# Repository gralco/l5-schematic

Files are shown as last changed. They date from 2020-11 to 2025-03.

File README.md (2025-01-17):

# l5-schematic

The Librem 5 schematics and layout files (mainboard, USB-C board, and USB-C FPC flex cable).

The [EDA CAD files](./CAD/) included are the [PADS](./CAD/PADS/) schematic and layout that were used to produce the Librem 5 boards,
as well as [KiCad](./CAD/KiCad/) files which are a converted capture of the PADS design that are in a reliable reference draft state.

## License
[GNU GPLv3+](./LICENSE)

## Mechanical Designs
The Librem 5's mechanical designs can be found in the [Librem5/3D_designs](https://source.puri.sm/Librem5/3D_designs) repo.

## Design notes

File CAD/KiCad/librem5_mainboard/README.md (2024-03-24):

# Librem 5 Mainboard KiCad Conversion
Project to convert the Librem 5 Mainboard to KiCad.

## License
GNU GPLv3+

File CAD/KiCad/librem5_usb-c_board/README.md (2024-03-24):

# Librem 5 USB-C Board KiCad Conversion
Project to convert the Librem 5 USB-C board to KiCad.

## License
GNU GPLv3+

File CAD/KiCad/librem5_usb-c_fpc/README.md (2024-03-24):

# Librem 5 USB-C FPC KiCad Conversion
Project to convert the Librem 5 USB-C FPC to KiCad.

## License
GNU GPLv3+

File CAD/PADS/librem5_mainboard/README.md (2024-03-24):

# Librem 5 Mainboard PADS
The Librem 5 Mainboard PADS CAD files.

## License
GNU GPLv3+

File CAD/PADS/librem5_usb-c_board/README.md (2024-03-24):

# Librem 5 USB-C Board PADS
The Librem 5 USB-C board PADS CAD files.

## License
GNU GPLv3+

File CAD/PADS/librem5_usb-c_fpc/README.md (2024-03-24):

# Librem 5 USB-C FPC PADS
The Librem 5 USB-C FPC PADS CAD files.

## License
GNU GPLv3+

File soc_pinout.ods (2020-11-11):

Net Name | Specific Alt Def | Ball name | PAD TYPE | Alt0 | Alt1 | Alt2 | Alt3 | Alt4 | Alt5 | Alt6 | Alt7
VSS | N/A | A2 | Ground
BT_WAKE | gpio4.IO[20] (interrupt) | A3 | GPIO | sai1.MCLK | sai5.MCLK | sai1.TX_BCLK |  |  | gpio4.IO[20] |  | sim_m.HRESP
FLASH_MOSI | ecspi1.MOSI | A4 | GPIO | ecspi1.MOSI | uart3.TX |  |  |  | gpio5.IO[7] |  | tpsmp.HDATA[9]
UART4_RTS | uart4.RTS_B | A5 | GPIO | ecspi2.SS0 | uart4.RTS_B |  |  |  | gpio5.IO[13] |  | tpsmp.HDATA[15]
UART3_RXD | uart3.RX | A6 | GPIO | uart3.RX | uart1.CTS_B |  |  |  | gpio5.IO[26] |  | tpsmp.HDATA[28]
UART1_TXD | uart1.TX | A7 | GPIO | uart1.TX | ecspi3.MOSI |  |  |  | gpio5.IO[23] |  | tpsmp.HDATA[25]
NC (pin USB2_RX_P) | NC | A8 | PHY
NC (pin USB2_TX_P) | NC | A9 | PHY
USB2_DP | N/A | A10 | PHY
USB1_RESREF | N/A | A11 | Ground
USB1_RXP | N/A | A12 | PHY
USB1_TXP | N/A | A13 | PHY
USB1_DP | N/A | A14 | PHY
DSI_DN3 | N/A | A15 | PHY
DSI_DN1 | N/A | A16 | PHY
DSI_DN0 | N/A | A17 | PHY
DSI_DN2 | N/A | A18 | PHY
CSI_P2_CKN | N/A | A19 | PHY
CSI_P2_DN1 | N/A | A20 | PHY
CSI_P2_DN2 | N/A | A21 | PHY
CSI_P1_CKN | N/A | A22 | PHY
CSI_P1_DN0 | N/A | A23 | PHY
VSS | N/A | A24 | Ground
VSS | N/A | B1 | Ground
Unpurposed (BOOT_CFG10/SAI1_TXD2) | gpio4.IO[14] (output LOW) | B2 | GPIO | sai1.TX_DATA[2] | sai5.TX_DATA[2] |  |  | coresight.TRACE[10] | gpio4.IO[14] | ccmsrcgpcmix.BOOT_CFG[10] | sim_m.HADDR[29]
Unpurposed (BOOT_CFG14/SAI1_TXD6) | gpio4.IO[18] (output LOW) | B3 | GPIO | sai1.TX_DATA[6] | sai6.RX_SYNC | sai6.TX_SYNC |  | coresight.TRACE[14] | gpio4.IO[18] | ccmsrcgpcmix.BOOT_CFG[14] | sim_m.HBURST[1]
FLASH_MISO | ecspi1.MISO | B4 | GPIO | ecspi1.MISO | uart3.CTS_B |  |  |  | gpio5.IO[8] |  | tpsmp.HDATA[10]
UART4_CTS | uart4.CTS_B | B5 | GPIO | ecspi2.MISO | uart4.CTS_B |  |  |  | gpio5.IO[12] |  | tpsmp.HDATA[14]
UART2_RXD | uart2.RX | B6 | GPIO | uart2.RX | ecspi3.MISO |  |  |  | gpio5.IO[24]
UART3_TXD | uart3.TX | B7 | GPIO | uart3.TX | uart1.RTS_B |  |  |  | gpio5.IO[27] |  | tpsmp.HDATA[29]
NC (pin USB2_RX_N) | NC | B8 | PHY
NC (pin USB2_TX_N) | NC | B9 | PHY
USB2_DN | N/A | B10 | PHY
USB2_RESREF | N/A | B11 | Ground
USB1_RXN | N/A | B12 | PHY
USB1_TXN | N/A | B13 | PHY
USB1_DN | N/A | B14 | PHY
DSI_DP3 | N/A | B15 | PHY
DSI_DP1 | N/A | B16 | PHY
DSI_DP0 | N/A | B17 | PHY
DSI_DP2 | N/A | B18 | PHY
CSI_P2_CKP | N/A | B19 | PHY
CSI_P2_DP1 | N/A | B20 | PHY
CSI_P2_DP2 | N/A | B21 | PHY
CSI_P1_CKP | N/A | B22 | PHY
CSI_P1_DP0 | N/A | B23 | PHY
CSI_P1_DN2 | N/A | B24 | PHY
VSS | N/A | B25 | Ground
Unpurposed (BOOT_CFG15/SAI1_TXD7) | gpio4.IO[19] (output LOW) | C1 | GPIO | sai1.TX_DATA[7] | sai6.MCLK |  |  | coresight.TRACE[15] | gpio4.IO[19] | ccmsrcgpcmix.BOOT_CFG[15] | sim_m.HBURST[2]
SAI6_TXD0 (BOOT_CFG13) | sai6.TX_DATA[0] | C2 | GPIO | sai1.TX_DATA[5] | sai6.RX_DATA[0] | sai6.TX_DATA[0] |  | coresight.TRACE[13] | gpio4.IO[17] | ccmsrcgpcmix.BOOT_CFG[13] | sim_m.HBURST[0]
SAI3_TXD | sai3.TX_DATA[0] | C3 | GPIO | sai3.TX_DATA[0] | gpt1.CAPTURE3 | sai5.RX_DATA[3] |  |  | gpio5.IO[1]
SAI3_TXC | sai3.TX_BCLK | C4 | GPIO | sai3.TX_BCLK | gpt1.CAPTURE2 | sai5.RX_DATA[2] |  |  | gpio5.IO[0]
UART4_RXD | uart4.RX | C5 | GPIO | ecspi2.SCLK | uart4.RX |  |  |  | gpio5.IO[10] |  | tpsmp.HDATA[12]
SPI_SS1 | gpio5.IO[28] (output) | C6 | GPIO | uart4.RX | uart2.CTS_B | pcie1.CLKREQ_B |  |  | gpio5.IO[28]
UART1_RXD | uart1.RX | C7 | GPIO | uart1.RX | ecspi3.SCLK |  |  |  | gpio5.IO[22] |  | tpsmp.HDATA[24]
VSS | N/A | C8 | Ground
USB2_ID | N/A | C9 | PHY
VSS | N/A | C10 | Ground
USB2_VPTX | N/A | C11 | Power
USB1_VPTX | N/A | C12 | Power
VSS | N/A | C13 | Ground
USB1_ID | N/A | C14 | PHY
VSS | N/A | C15 | Ground
DSI_CKN | N/A | C16 | PHY
MIPI_DSI_REXT | N/A | C17 | Ground
MIPI_VDDHA1 | N/A | C18 | Power
CSI_P2_DN3 | N/A | C19 | PHY
CSI_P2_DN0 | N/A | C20 | PHY
CSI_P1_DN3 | N/A | C21 | PHY
CSI_P1_DN1 | N/A | C22 | PHY
CSI_P1_DP2 | N/A | C23 | PHY
VSS | N/A | C24 | Ground
PCIE2_RESREF | N/A | C25 | NC
Unpurposed (BOOT_CFG11/SAI1_TXD3) | gpio4.IO[15] (output LOW) | D1 | GPIO | sai1.TX_DATA[3] | sai5.TX_DATA[3] |  |  | coresight.TRACE[11] | gpio4.IO[15] | ccmsrcgpcmix.BOOT_CFG[11] | sim_m.HADDR[30]
SAI6_RXC (BOOT_CFG12) | sai6.RX_BCLK | D2 | GPIO | sai1.TX_DATA[4] | sai6.RX_BCLK | sai6.TX_BCLK |  | coresight.TRACE[12] | gpio4.IO[16] | ccmsrcgpcmix.BOOT_CFG[12] | sim_m.HADDR[31]
LED_G | pwm4.OUT | D3 | GPIO | sai3.MCLK | pwm4.OUT | sai5.MCLK |  |  | gpio5.IO[2]
FLASH_SS | ecspi1.SS0 | D4 | GPIO | ecspi1.SS0 | uart3.RTS_B |  |  |  | gpio5.IO[9] |  | tpsmp.HDATA[11]
FLASH_SCK | ecspi1.SCLK | D5 | GPIO | ecspi1.SCLK | uart3.RX |  |  |  | gpio5.IO[6] |  | tpsmp.HDATA[8]
UART2_TXD | uart2.TX | D6 | GPIO | uart2.TX | ecspi3.SS0 |  |  |  | gpio5.IO[25]
SMC_BOOT0 | gpio5.IO[29] (output) | D7 | GPIO | uart4.TX | uart2.RTS_B | pcie2.CLKREQ_B |  |  | gpio5.IO[29]
NVCC_UART | N/A | D8 | Power
USB2_VBUS | N/A | D9 | PHY
VSS | N/A | D10 | Ground
USB2_VP | N/A | D11 | Power
USB1_VP | N/A | D12 | Power
VSS | N/A | D13 | Ground
USB1_VBUS | N/A | D14 | PHY
VSS | N/A | D15 | Ground
DSI_CKP | N/A | D16 | PHY
MIPI_VDDHA2 | N/A | D17 | Power
MIPI_VDDHA3 | N/A | D18 | Power
CSI_P2_DP3 | N/A | D19 | PHY
CSI_P2_DP0 | N/A | D20 | PHY
CSI_P1_DP3 | N/A | D21 | PHY
CSI_P1_DP1 | N/A | D22 | PHY
VSS | N/A | D23 | Ground
NC (pin PCIE2_RXN_N) | NC | D24 | PHY
NC (pin PCIE2_RXN_P) | NC | D25 | PHY
NFC_IRQ | gpio4.IO[11] (interrupt) | E1 | GPIO | sai1.TX_BCLK | sai5.TX_BCLK |  |  | coresight.EVENTI | gpio4.IO[11] |  | sim_m.HADDR[26]
Unpurposed (BOOT_CFG09/SAI1_TXD1) | gpio4.IO[13] (output LOW) | E2 | GPIO | sai1.TX_DATA[1] | sai5.TX_DATA[1] |  |  | coresight.TRACE[9] | gpio4.IO[13] | ccmsrcgpcmix.BOOT_CFG[9] | sim_m.HADDR[28]
NVCC_SAI3 | N/A | E3 | Power
VSS | N/A | E4 | Ground
UART4_TXD | uart4.TX | E5 | GPIO | ecspi2.MOSI | uart4.TX |  |  |  | gpio5.IO[11] |  | tpsmp.HDATA[13]
MOTO (haptic) | pwm1.OUT | E6 | GPIO | spdif1.EXT_CLK | pwm1.OUT |  |  |  | gpio5.IO[5] |  | tpsmp.HDATA[7]
I2C1_SCL_1V8 | i2c1.SCL | E7 | GPIO | i2c1.SCL | enet1.MDC |  |  |  | gpio5.IO[14] |  | tpsmp.HDATA[16]
I2C1_SDA_1V8 | i2c1.SDA | E8 | GPIO | i2c1.SDA | enet1.MDIO |  |  |  | gpio5.IO[15] |  | tpsmp.HDATA[17]
I2C3_SDA | i2c3.SDA | E9 | GPIO | i2c3.SDA | pwm3.OUT | gpt3.CLK |  |  | gpio5.IO[19] |  | tpsmp.HDATA[21]
VSS | N/A | E10 | Ground
USB2_DVDD | N/A | E11 | Power
USB1_DVDD | N/A | E12 | Power
VSS | N/A | E13 | Ground
VSS | N/A | E14 | Ground
MIPI_VDD1 | N/A | E15 | Power
VSS | N/A | E16 | Ground
MIPI_VDDA1 | N/A | E17 | Power
MIPI_VDDA2 | N/A | E18 | Power
VSS | N/A | E19 | Ground
VSS | N/A | E20 | Ground
VSS | N/A | E21 | Ground
VSS | N/A | E22 | Ground
VSS | N/A | E23 | Ground
NC (pin PCIE2_TXN_N) | NC | E24 | PHY
NC (pin PCIE2_TXN_P) | NC | E25 | PHY
SAI6_RXD0 (BOOT_CFG05) | sai6.RX_DATA[0] | F1 | GPIO | sai1.RX_DATA[5] | sai6.TX_DATA[0] | sai6.RX_DATA[0] | sai1.RX_SYNC | coresight.TRACE[5] | gpio4.IO[7] | ccmsrcgpcmix.BOOT_CFG[5] | sim_m.HADDR[22]
Unpurposed (BOOT_CFG08/SAI1_TXD0) | gpio4.IO[12] (output LOW) | F2 | GPIO | sai1.TX_DATA[0] | sai5.TX_DATA[0] |  |  | coresight.TRACE[8] | gpio4.IO[12] | ccmsrcgpcmix.BOOT_CFG[8] | sim_m.HADDR[27]
SAI3_RXD | sai3.RX_DATA[0] | F3 | GPIO | sai3.RX_DATA[0] | gpt1.CAPTURE1 | sai5.RX_DATA[0] |  |  | gpio4.IO[30]
WIFI_REG_ON | gpio4.IO[29] (output) | F4 | GPIO | sai3.RX_BCLK | gpt1.CAPTURE2 | sai5.RX_BCLK |  |  | gpio4.IO[29] |  | tpsmp.HTRANS[1]
NVCC_ECSPI | N/A | F5 | Power
LED_R | pwm3.OUT | F6 | GPIO | spdif1.OUT | pwm3.OUT |  |  |  | gpio5.IO[3] |  | tpsmp.HDATA[5]
I2C2_SDA | i2c2.SDA | F7 | GPIO | i2c2.SDA | enet1.1588_EVENT1_OUT |  |  |  | gpio5.IO[17] |  | tpsmp.HDATA[19]
I2C4_SCL | i2c4.SCL | F8 | GPIO | i2c4.SCL | pwm2.OUT | pcie1.CLKREQ_B |  |  | gpio5.IO[20] |  | tpsmp.HDATA[22]
I2C4_SDA | i2c4.SDA | F9 | GPIO | i2c4.SDA | pwm1.OUT | pcie2.CLKREQ_B |  |  | gpio5.IO[21] |  | tpsmp.HDATA[23]
VSS | N/A | F10 | Ground
USB2_VPH | N/A | F11 | Power
USB1_VPH | N/A | F12 | Power
VSS | N/A | F13 | Ground
VSS | N/A | F14 | Ground
MIPI_VDD1 | N/A | F15 | Power
VSS | N/A | F16 | Ground
MIPI_VDDA3 | N/A | F17 | Power
MIPI_VDDA4 | N/A | F18 | Power
MIPI_VDDPLL | N/A | F19 | Power
VSS | N/A | F20 | Ground
CHG_INT | gpio3.IO[3] (interrupt) | F21 | GPIO | rawnand.CE2_B | qspi.B_SS0_B |  |  |  | gpio3.IO[3]
PCIE_VP2 | N/A | F22 | NC
PCIE_VPTX2 | N/A | F23 | NC
NC (pin PCIE2_REF_PAD_CLK_N) | NC | F24 | PHY
NC (pin PCIE2_REF_PAD_CLK_P) | NC | F25 | PHY
Unpurposed (BOOT_CFG07/SAI1_RXD7) | gpio4.IO[9] (output LOW) | G1 | GPIO | sai1.RX_DATA[7] | sai6.MCLK | sai1.TX_SYNC | sai1.TX_DATA[4] | coresight.TRACE[7] | gpio4.IO[9] | ccmsrcgpcmix.BOOT_CFG[7] | sim_m.HADDR[24]
SAI6_RXFS (BOOT_CFG06) | sai6.RX_SYNC | G2 | GPIO | sai1.RX_DATA[6] | sai6.TX_SYNC | sai6.RX_SYNC |  | coresight.TRACE[6] | gpio4.IO[8] | ccmsrcgpcmix.BOOT_CFG[6] | sim_m.HADDR[23]
SAI3_TXFS | sai3.TX_SYNC | G3 | GPIO | sai3.TX_SYNC | gpt1.CLK | sai5.RX_DATA[1] |  |  | gpio4.IO[31]
NFC_EN | gpio4.IO[28] | G4 | GPIO | sai3.RX_SYNC | gpt1.CAPTURE1 | sai5.RX_SYNC |  |  | gpio4.IO[28]
SAI2_TXD | sai2.TX_DATA[0] | G5 | GPIO | sai2.TX_DATA[0] | sai5.TX_DATA[3] |  |  |  | gpio4.IO[26] |  | tpsmp.CLK
SPDIF_RX | gpio5.IO[4] (output) | G6 | GPIO | spdif1.IN | pwm2.OUT |  |  |  | gpio5.IO[4] |  | tpsmp.HDATA[6]
I2C2_SCL | i2c2.SCL | G7 | GPIO | i2c2.SCL | enet1.1588_EVENT1_IN |  |  |  | gpio5.IO[16] |  | tpsmp.HDATA[18]
I2C3_SCL | i2c3.SCL | G8 | GPIO | i2c3.SCL | pwm4.OUT | gpt2.CLK |  |  | gpio5.IO[18] |  | tpsmp.HDATA[20]
VSS | N/A | G9 | Ground
VSS | N/A | G10 | Ground
USB2_VDD33 | N/A | G11 | Power
USB1_VDD33 | N/A | G12 | Power
VSS | N/A | G13 | Ground
VDD_ARM | N/A | G14 | Power
VDD_ARM | N/A | G15 | Power
VDD_ARM | N/A | G16 | Power
VSS | N/A | G17 | Ground
VSS | N/A | G18 | Ground
NC (pin NAND_ALE) | gpio3.IO[0] (output LOW) | G19 | GPIO | rawnand.ALE | qspi.A_SCLK |  |  |  | gpio3.IO[0] |  | sim_m.HPROT[0]
NC (pin NAND_DATA00) | gpio3.IO[6] (output LOW) | G20 | GPIO | rawnand.DATA00 | qspi.A_DATA[0] |  |  |  | gpio3.IO[6]
CHG_EN | gpio3.IO[2] (output) | G21 | GPIO | rawnand.CE1_B | qspi.A_SS1_B |  |  |  | gpio3.IO[2] |  | sim_m.HPROT[2]
PCIE_VP1 | N/A | G22 | NC
PCIE_VPTX1 | N/A | G23 | NC
VSS | N/A | G24 | Ground
PCIE1_RESREF | N/A | G25 | NC
HSW_WIFI_STATE | gpio4.IO[10] (input) | H1 | GPIO | sai1.TX_SYNC | sai5.TX_SYNC |  |  | coresight.EVENTO | gpio4.IO[10] |  | sim_m.HADDR[25]
Unpurposed (BOOT_CFG02/SAI1_RXD2) | gpio4.IO[4] (output LOW) | H2 | GPIO | sai1.RX_DATA[2] | sai5.RX_DATA[2] |  |  | coresight.TRACE[2] | gpio4.IO[4] | ccmsrcgpcmix.BOOT_CFG[2] | sim_m.HADDR[19]
NC (pin SAI2_RXC) | gpio4.IO[22] (output LOW) | H3 | GPIO | sai2.RX_BCLK | sai5.TX_BCLK |  |  |  | gpio4.IO[22] |  | sim_m.HSIZE[1]
SAI2_TXFS | sai2.TX_SYNC | H4 | GPIO | sai2.TX_SYNC | sai5.TX_DATA[1] |  |  |  | gpio4.IO[24] |  | sim_m.HWRITE
SAI2_MCLK | sai2.MCLK | H5 | GPIO | sai2.MCLK | sai5.MCLK |  |  |  | gpio4.IO[27] |  | tpsmp.HDATA_DIR
SAI2_RXD | sai2.RX_DATA[0] | H6 | GPIO | sai2.RX_DATA[0] | sai5.TX_DATA[0] |  |  |  | gpio4.IO[23] |  | sim_m.HSIZE[2]
NVCC_I2C | N/A | H7 | Power
VSS | N/A | H8 | Ground
VSS | N/A | H9 | Ground
VSS | N/A | H10 | Ground
VSS | N/A | H11 | Ground
VSS | N/A | H12 | Ground
VSS | N/A | H13 | Ground
VDD_ARM | N/A | H14 | Power
VDD_ARM | N/A | H15 | Power
VDD_ARM | N/A | H16 | Power
VSS | N/A | H17 | Ground
VSS | N/A | H18 | Ground
4G_RESET# | gpio3.IO[1] (output) | H19 | GPIO | rawnand.CE0_B | qspi.A_SS0_B |  |  |  | gpio3.IO[1] |  | sim_m.HPROT[1]
CHG_OTG_OUT_EN | gpio3.IO[4] (output) | H20 | GPIO | rawnand.CE3_B | qspi.B_SS1_B |  |  |  | gpio3.IO[4] |  | sim_m.HADDR[0]
PWR_KEY | gpio3.IO[5] (interrupt) | H21 | GPIO | rawnand.CLE | qspi.B_SCLK |  |  |  | gpio3.IO[5] |  | sim_m.HADDR[1]
NC (pin NAND_DATA02) | gpio3.IO[8] (output) | H22 | GPIO | rawnand.DATA02 | qspi.A_DATA[2] |  |  |  | gpio3.IO[8] |  | sim_m.HADDR[4]
PCIE_VPH1 | N/A | H23 | NC
NC (pin PCIE1_RXN_N) | NC | H24 | PHY
NC (pin PCIE1_RXN_P) | NC | H25 | PHY
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

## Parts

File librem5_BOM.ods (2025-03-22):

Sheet: main board
Manufacturer’s Part Number | Designator | Description | Qty per Board | Also on USB-C Board?
02015A6R8CAT2A | C332,C333 | CAP CER 6.8PF 50V ±0.5P COG 0201 | 2
02016D105MAT4A | C20,C21,C22,C23,C24,C27,C28,C29,C31,C32,C34,C35,C36,C38,C40,C42,C57,C58,C75,C79,C80,C94,C98,C99,C101,C103,C104,C105,C106,C107,C109,C111,C112,C113,C118,C119,C120,C121,C122,C123,C124,C125,C126,C127,C128,C131,C132,C134,C139,C140,C143,C144,C145,C146,C153,C154,C155,C156,C157,C158,C159,C160,C161,C162,C163,C164,C177,C200,C218,C219,C223,C224,C225,C226,C228,C230,C243,C257,C274,C275,C291,C292,C295,C296,C298,C301,C302,C304,C317,C318,C323,C326,C331,C346,C347,C348,C350,C351,C352,C354,C356,C370,,C381,C384,C385,C386,C387,C388,C389,C390,C393,C394,C395,C396,C397,C398,C399,C400,C401,C406,C407,C408,C409,C410,C411,C412,C413,C414,C415,C416,C417,C418,C419,C420,C421,C422,C423,C424,,C425,C426,C427,C428,C429,C430,C431,C432,C433,C436,C437,C438,C439,C440,C441,C442,C443,C444,C445,C446,C514,C516,C517,C522,C523,C541,C611,C717,C728,C746,C901,C1323,C2191 | CAP CER 1uF 6V3 20% X5R 0201 | 173 | Yes
0201X102K500CT | C342 | CAP CER 0.01uF 35V 20% X5R 0201 | 1
04023D225KAT2A | C60,C61,C62,C68,C69,C239,C249,C341,C375 | CAP CER 2.2uF 25V 20% X5R 0402 | 9 | Yes
04026D475KAT2A | C4,C5,C9,C10,C11,C12,C30,C37,C39,C45,C46,C47,C59,C70,C73,C74,C78,C92,C96,C97,C202,C203,C204,C205,C207,C208,C209,C210,C212,C213,C214,C215,C217,C222,C227,C229,C238,C241,C242,C250,C251,C252,C260,C269,C272,C273,C276,C282,C286,C294,C297,C303,C310,C311,C312,C337,C360,C382,C480,C513,C542,C601,C605,C729,C737,C743,C747,C749,C750,C751,C754,C755,C757,C759,C852,C1251 | CAP CER 4.7uF 6V3 20% X5R 0402 | 76
06033D106MAT2A | C49,C55,C232,C233,C234,C287,C319,C363,C364,C518,C519,C740 | CAP CER 10uF 25V 20% X5R 0603 | 12
06036D226MAT2A | C7,C13,C14,C15,C16,C17,C18,C43,C54,C56,C65,C67,C77,C83,C116,C165,C166,C167,C168,C169,C170,C171,C172,C173,C174,C175,C176,C201,C206,C211,C220,C231,C240,C245,C246,C247,C248,C253,C258,C277,C281,C283,C284,C285,C288,C289,,C290,C299,C300,C306,C308,C313,C324,C327,C329,C330,C335,C336,,C448,C449,C450,C521,C526,C710,C722,C723,C725,C731,C736,C739,C741,C742,C745,C753,C760,C769,C775 | CAP CER 22uF 6V3 20% X5R 0603 | 79
AP2281-1FMG-7 | U12,U38,U46,U48 | IC SWITCH 80mohm 1.5-6V AP2281-1FMG | 4
AP2281-3FMG-7 | U4,U23,U40,U41,U43,U44 | IC SWITCH 80mohm 1.5-6V AP2281-3FMG | 6
B39162B4327P810 | Z1 | SAW RF FILTER B39163B4327P810 (Type B4327) QCS5P | 1
B5817WS-TP | D1,D2,D4,D5 | DIODE Schottky Barrier Diode SOD323 | 4
BD71837AMWV-E2 | U1 | IC POWER MANAGEMENT BUCK 8CH LDO 7CH-0.3-5.5V BD71837AMWV | 1
BGA725L6 | U20 | IC Silicon Germanium Low Noise Amplifie BGA725L6 | 1
BQ25895RTWT | U14 | IC i2c Controlled Single Cell 5A Fast Charger for High Input Voltge | 1
BSS138PW | Q12 | 60 V, 320 mA N-channel Trench MOSFET | 1
PESD3V3S1UL | TVS1,TVS2,TVS4,TVS5,TVS6,TVS7,TVS8,TVS9,TVS10,TVS12,TVS13,TVS14,TVS15,TVS16,TVS17,TVS18,TVS21,TVS22,TVS24,TVS25,TVS26,TVS27,TVS53,TVS54,TVS55,TVS56 | IC ESD 3V3 200pF 30KV SOD882 PESD3V3S1UL | 26
3SM222FMT1KA | U31 | IC CMOS MEMS microphone | 1 | Yes
TLV75801PDBVR | U21,U37 | IC LDO 1.5V-6.0V 500mA 0.55--5.5V TLV75801PDBVR | 2
ME6211C28M5G | U7 | IC Voltage LDO sot23-5 0.5A Vin:5.5V Vout:2.8V MARK:G1 or S1xx ME6211C28M5G MicrOne | 1
UM805RE | U704 | IC VOLT MONITOR 2.63V VTH RST 1-5.5V SOT143 | 1
W25Q16JVUXIM or GD25Q16EEIGR | U147 | IC 3V 16Mbit SPI FLASH W25Q16JVUXIM | 1
AH3663 | U300 | IC Hall sensor AH3663 SMT SOT23 | 1
LSM9DS1 | U16 | IC 9-axis sensor[LSM9DS1] | 1
AMPI0618ED2R2MT | L46 | IND PWR 2.2UH@100KHZ Isat:8A 20% SMT | 1
CQ3610BL-100 | U47 | MOTO 2.7V 14000rpm 75mA 33ohm | 1
AP2302 | Q19 | TRANS MOSFET N-CH 16V 3.6A SOT-23 | 1
RYU002N05 | Q1,Q2,Q3,Q4,Q5,Q6,Q7,Q8,Q9,Q10,Q11,Q13,Q14,Q18 | TRAN NMOS SWPU-C-MN-U1J002-S10-1-R02 0.9V DRIVE 50V UMT3 | 14
CON-6PIN-OK-501F006-13 | J1 | SOCKET Board-to-FPC 1.3mm 6pin H=0.9mm | 1
24-5857-040 | J12 | SOCKET BTB 0.35mm 40pin H=0.7mm 5857 | 1 | Yes
OK-06F024-04 | J4,J10 | SOCKET Board-to-FPC 0.4mm 24pin H=1.0mm | 2
OK-06F034-04 | J6,J22 | SOCKET Board-to-FPC 0.4mm 34pin H=1.0mm | 2
APCI0136-P001A | J5 | CON M.2 67PIN E-KEY 0.5mm; H4.8 | 1
PTC3121N | E1,E2,E3,E4,E5,E6,E7,E8,E9,E10,E11,E12,E13,E14,E15,E16,E17,E18,E19,E20,E21,E22,E23,E24,E25,E26,E27,E28,E29,E30,E31,E32,E33,E34,E35,E36,E37 | shield can clip,6.5mmX0.8mmX 1.28 mm | 37
SA0701127150-105 | J9 | 1.5OH 7P PUSH MICRO SIM CARD | 1
SA2101110135-01 | J7 | 1.35H 3 CHOOSE 2 CARD SIM+TF | 1
CLIP-1.1H | JV1,JV2 | Cable line clip,SUS,φ0.8mm,1.5X1.2.X1.1mm | 2
BA32-111203-01 | J20 | 3PIN BATTERY CONN H=3.2mm SMT H=1.2mm P=2.5mm | 1
MK-12C02-G015 | SW3,SW5,SW7 | SW SLIDE 7PIN G1.5mm switch | 3
T2-240003-BFD-1-000 | Y3 | CLOCK Crystal 24MHz 18pF +-20PPM/ | 1
X2B02500BI1H-U | Y401 | CLOCK Crystal 25MHz 9pF +-30PPM/ | 1
T2-270003-BKE-1-000 | Y402 | CLOCK Crystal 27MHz 9pF +-30PPM/ | 1
ECS-.327-CDX-1128 | Y2 | CLOCK Crystal 32.768KHz-Load Capacitance 6PF,± 20PPM | 1
T2-327680-CDD-1-000 | Y1 | CLOCK Crystal 1.5~3.6V ASH7K-32.768KHz-12.5pF+-20PPM 3.2x1.5x1mm | 1
NX5427001Z | Y501 | OSC 27MHz HCSL 3.3V 5X3.2MM SMT | 1
C0603X5R1E102K030BA | C452 | CAP CER 1nF 25 10% X5R 0201 | 1
C1005X5R1E224K050BC | C235,C237,,C315,C320,C321,C365,C376,C378,C535 | CAP CER 0.22uF 25V 20% X5R 0402 | 10
CBR02C100J5GAC | C244,C278 | CAP CER 10PF 25V 5% COG 0201 | 2
CGA1A2C0G1H560J030BA | C87,C256,C451,C454 | CAP CER 56pF 50Vdc 5% C0G C0201 | 4
CGA3E2X5R1E224K080AA | C305 | CAP CER 0.22uF 35V 20% X5R 0603 | 1
CL10A225KL8NNNC | C76 | CAP CER 2.2uF 35V 20% X5R 0603 | 1
CR0201FW-33R0GLF | R10,R13,R14,R16,R18,R43,R44,,R181,R211,R525,R552 | Resistor Chip 0201 33R Ohm 1/20W 1% | 12
CRCW0201100KFKED | R35,R36,R71,R72,R100,R103,R120,R189,R223,R244,R245,R419,R508,R509,R529,R545,R831,R837,R904,R933,R934 | Resistor Chip 0201 100K Ohm 1/20W 1% | 21 | Yes
CRCW0201100RFKED | R26,R176,R132,,R185,R236,R239,R625,R626,R627 | Resistor Chip 0201 100R Ohm 1/20W 1% | 10
CRCW020110K0FNED | R4,R7,R8,R9,R11,R12,R15,R17,R19,R20,R22,R23,R24,R32,R48,R52,R53,R66,R69,R92,,R105,R107,R108,R113,R114,R141,R143,R145,R147,R148,R149,R151,R155,R157,R164,R165,R169,R170,R196,R206,R207,R208,R212,R217,R220,R224,R229,R233,R235,R241,R242,R243,R248,R249,R263,R410,R416,R507,R803,R811,R815 | Resistor Chip 0201 10K Ohm 1/20W 1% | 62 | Yes
CRCW020110R0FNED | R5,R6,R61,R104,R127,R177,R216,R219,R221,R225,R226,R230,R231,,L13,L15,L19,L25,L26,L29,L30,L39 | Resistor Chip 0201 10R Ohm 1/20W 1% | 22
CRCW020111K8FKED | R33 | Resistor Chip 0201 11.8K Ohm 1/20W 1% | 1
CRCW020112K0FKED | R40,R88 | Resistor Chip 0201 12K Ohm 1/20W 1% | 2
CRCW0201150RFNED | R201,R202 | Resistor Chip 0201 150R Ohm 1/20W 1% | 2
CRCW02011K00FNED | R51,R59,R60,R85,R86,R98,R99,R119,R121,R128,R142,R146,R150,R156,R174,R175,R178,R191,,R213,R624 | Resistor Chip 0201 1K Ohm 1/20W 1% | 21
CRCW02011K50FKED | R209,R210 | Resistor Chip 0201 1.5K Ohm 1/20W 1% | 2
CRCW02011M00FKED | R42,R54,R251,R252 | Resistor Chip 0201 1M Ohm 1/20W 1% | 4
CRCW0201240RFNED | R203,R204,R205 | Resistor Chip 0201 240R Ohm 1/20W 1% | 3
CRCW020127K0FKED | R58,R122,R200 | Resistor Chip 0201 27K Ohm 1/20W 1% | 3
CRCW02012K20FKED | R95,R97,R129,R190,R199,R301,R302,R303,R304,R305,R306,R307,R308 | Resistor Chip 0201 2.2K Ohm 1/20W 1% | 13
CRCW020130K1FKED | R89,R116,R289 | Resistor Chip 0201 30.1K Ohm 1/20W 1% | 3
CRCW0201470KFKED | R215,R903 | Resistor Chip 0201 470K Ohm 1/20W 1% | 2
CRCW020147K0FNED | R31,R37,R46,R55,R56,R67,R68,R83,R84,R93,R96,R101,R102,R123,R125,R131,R133,R158,R159,R160,R179,R192,R193,R194,R214,R218,R227,R232,R237,R250,R554,R825,R827,R828,R829,R832,R833,R834,R835,R836,R839,R840 | Resistor Chip 0201 47K Ohm 1/20W 1% | 42
CRCW0201499RFKED | R503 | Resistor Chip 0201 499 Ohm 1/20W 1% | 1
CRCW02014K70FKED | R2,R3,R409,R601,R602,R603 | Resistor Chip 0201 4.7K Ohm 1/20W 1% | 6
CRCW0201560KFKED | R186,R902 | Resistor Chip 0201 560K Ohm 1/20W 1% | 2
CRCW02015K23FKED | R117 | Resistor Chip 0201 5.23K Ohm 1/20W 1% | 1
CRCW02019K09FKED | R70 | Resistor Chip 0201 9.09K Ohm 1/20W 1% | 1
CRCW04021R00FKEDC | L8,L11,L16,L80 | Resistor Chip 0402 1 Ohm 1/16W 1% | 4
600-10429-01_L | CON13 | RF shrapnel,W=1.6mm,L=3.6mm,H=1.78mm | 1
AT10-110001-01 | CON7,CON8,CON11,CON12 | RF shrapnel,W=1.4mm,L=2.4mm,Hf=1.0±0.1mm,Hw=0.55mm | 4 | Yes
AT0331-R | CON1 | ANTENNA RF SPRING SMT | 1
ECT818000500 | ANT1,ANT2 | CON RF IV 2X2X0.6 R=1.5 r=0.45 | 2 | Yes
ERJ-1GN0R00C | R1,R28,R30,R34,R41,R45,R47,R49,R50,R57,R65,R73,R74,R75,R76,R77,R78,R79,R80,R81,R87,R90,R94,R109,R111,R112,R124,R139,R144,R161,R162,R166,R187,R197,R234,R238,R240,R247,R254,R255,R256,R259,R260,R261,R510,R511,R569,R573,R616,R617,R621,R940,R941,R2101,L34,L35,C261,C262,C263,C264,C265,C266,C267,C268,C361,C362,C367,C368 | Resistor Chip 0201 0R Ohm 1/20W 1% | 68 | Yes
ERJ-U01F1602C | R163 | Resistor Chip 0201 16K Ohm 1/20W 1% | 1
GRM0335C1H121JA01D | C88,C453 | CAP CER 120PF 25V 10% NPO 0201 | 2
GRM0335C1HR50BA01D | C53 | CAP CER 0.5PF 50V C0G/NP0 0201 | 1
GRM033R60J104KE19J | C1,C2,C3,C6,C8,C19,C25,C26,C44,C48,C51,C63,C64,C66,C71,C72,C81,C82,C84,C93,C95,C102,C142,C147,C148,C149,C150,C151,C152,C178,C179,C180,C182,C184,C185,C186,C187,C188,C189,C190,C191,C192,C193,C194,C195,C196,C197,C198,C199,C216,C221,C254,C293,C307,C309,C314,C325,C328,C334,C338,C339,C344,C345,C349,C353,C355,C357,C358,C359,C366,C369,C371,C372,C373,C374,C379,C380,C501,C512,C520,C534,C602,C603,C604,C606,C607,C610,C758,C4051 | Ceramic Cap,X5R,0.10μF±10%,6.3Vdc,0201 | 89 | Yes
GRM033R71E221KA01D | C343,C377 | CAP CER 220PF 25V 10% X7R 0201 | 2
HD3SS460RNHR | U30 | IC USB TYPE-C Alternate Mode MUX IC/USB | 1
HKQ0603W27NH-T or LQP03HQ27NH02D | R136 | FIXED IND 27NH 160MA 1.6 OHM SMD | 1
HPZ1005U121-1R1TF | L1,L14,L18,L23,L27,L31,L38,L40,L41,L42,L47,L48,L49,L54,L55,L57,L65,L82 | FB 120ohm@100MHz 100ohm@1GHz DCR0.13ohm 1.1A T:0.5mm | 18 | Yes
IP4252CZ8-4-TTL | F1,F3,F4,F5,F6,F7,F8,F9,F10,F11,F13,F14,F115 | IC ESD Filter 40 ohm 12pF 4CH/ IP4252CZ8-4 | 13
JA-36A2-111 | J2 | 3.6H 5PIN 4POLE DIP TYPE JA-36A2-111_REV_1B | 1
APCI0103-P001A | J3 | CON M.2 67PIN B-KEY 0.5mm; H4.8 | 1
LDCL015MR | U33,,U78 | IC LDO 1.8V-5.5V 150mA 0.8--5.5V LDCL015MR | 3
LM3560TLE-20/NOPB | U8 | IC FLASH Driver Dual 1A LM3560 | 1
LM36922YFFR | U42 | IC High-Brightness,Dual-string White LED Driver LM36922 | 1
LQP03TG5N6H02D | L68 | Ceramic inductor,5.6nH±3%,250mA,Q18,0.88Ω,6000MHz,0201 | 1
LRTBR98G-R5T-1+S7T7-35+PQ-25 | D27 | LED Multi CHIPLED | 1
MAX17055EWL+T | U15 | IC 7uA 1cell Fuel Gauge with ModelGauge m5 | 1
MEKK2520TR47M | L702,L703,L704,L705,L706,L707,L710 | IND PWR 0.47uH@1MHZ 4.7A 20% SMT | 7
MF-ASML050/6-2 | L79 | PTC RESET FUSE 6V 500MA 0402 | 1
MFC0603-R005FT5 | R180,R184,R312 | Resistor Chip 0603 5m Ohm 0.5W 1% | 3
MIMX8MQ6DVAJZAB | U101 | IC MIMX8MQ6DVAJZAB i.MX8M Quad Cortex-A53 Processors 1.5GHz | 1
MLG0603P9N1HT000 | C89,L3 | Ceramic inductor,9.1nH±5%,170mA,Q18,1.40Ω,4100MHz,0201 | 2
MT53E768M32D4DT-053 | U201 | IC MEM MOBILE LPDDR4 SDRAM 768 Meg x 32 4CH X16 I/O 1.1V AUTO VFBGA200 | 1 |  | NOTE: MT53D1024M32D4DT-053 4GB DRAM used on Liberty Phone
MZAH1005F352-R27TF | L50,L51,L60,L61,L62,L63 | FB 3500ohm@100MHz 1600ohm@1GHz DCR1ohm 270mA T:0.5mm | 6
MZAH1608G471-1R6TF | L4,L5,L6,L53,L66,L67,L92 | FB 470ohm@100MHz 350ohm@1GHz DCR0.075ohm 1.6A T:0.8mm | 7 | Yes
NSR20F30NXT5G | D25 | Schottky Barrier Diode 30V 2A NSR20F30NXT5G | 1
NTB0104GU12 | U5,U185 | IC Dual Supply Buffer 4BIT NTB0104GU12 | 2
NTR2101PT1G | Q1602 | TRAN PMOS POWER 79m OHM@-1.8V DRIVE -8V SOT23 | 1
NTSX2102GU8H | U68 | IC Dual supply translating transceiver NTSX2102 | 1
PCMF1USB3SZ | U6,U9,U18,U25 | IC EMI FILTER FOR DIFF CH W/ ESD PROTECTION 5V WLCSP5 PCMF1USB3S | 4
PCMF2USB3B/CZ | U10,U13,U45,U135,U136 | IC EMI FILTER FOR DIFF CH W/ ESD PROTECTION 5V WLCSP10 PCMF2USB3S | 5
PCMF3USB3SZ | U29,U117,U134 | IC EMI FILTER FOR DIFF CH W/ ESD PROTECTION 5V WLCSP15 PCMF3USB3S | 3
PESD12VV1BL | TVS23,TVS28 | IC ESD 5V0 45pF 30KV SOD882 PESD12VV1BL | 2
PESD5V0S1BL | TVS3,TVS29,TVS52,TVS58,TVS59 | IC ESD 5V0 45pF 30KV SOD882 | 5
PTVS30VS1UR | D10 | IC TVS 30V 400W | 1
PZ0603D241-R35TF | L43,L52 | FB 240ohm@100MHz DCR0.41ohm 0.35A T:0.3mm | 2
PZ3216D600-4R0TF | L9,L36,L58,L59 | FB 60ohm@100MHz DCR20mohm 4A T:0.85mm | 4
RB751G-40-TP | D3,D7,D8,D9,D11,D12,D13,D14,D15,D16,D17,D18,D19,D20,D21,D22,D23,D24,D28,D29 | Diode schottky SOD723 40V 30mA | 20
RC0201FR-0715KL | R163,R228,R288,R505 | Resistor Chip 0201 15K Ohm 1/20W 1% | 4 | Yes
RC0201FR-0718RL | R118,R126 | Resistor Chip 0201 18R Ohm 1/20W 1% | 2
RC0402FR-0710RL | L17,L22,L24,L33,L56,L64 | Resistor Chip 0402 10 Ohm 1/16W 1% | 6
RCWE0402R200FKEA | L7,L10,,L37,L45,L72,L76,L77 | Resistor Chip 0402 0.2 Ohm 1/16W 1% | 8
RV-4162-C7-32.768kHz-20PPM-TA-QC | U39 | IC SIM Card Power Supply With Level Translator TXS4555 | 1
SN74LVC1G125DCK3 | U11,U22,U55,U56 | IC Single Buffer With 3-state output | 4
STM32L432KCU3 | U329 | IC Arm Cotex M4 MCU+FPU,100DMIPS, 256KB FLASH,64KB SRAM, USB FS, STM32L432KC | 1
TESEO-LIV3F | U32 | IC GPS GLONASS, Galileo,BeiDu ,QZSS TESEO-LIV3F | 1
THGBMJG8C2LBAIL | U601 | IC MEM NAND FLASH 32GB MMC 5.1 THGBMHG8C2LBAIL FBGA153 | 1 |  | NOTE: THGAMRT0T43BAIR 128GB eMMC used on Liberty Phone
TLV3201AIDCKT | U909 | IC MicroPower Push-Pull Comparators 2.7V-5.5V SC70-5 TLV3201AIDCK | 1
TMK063B7103MP-F | C33,C52,C100,C108,C110,C114,C115,C117,C129,C130,C133,C135,C136,C137,C138,C236,C255,C316,C340,C447,C545 | CAP CER 0.01uF 25V 20% X5R 0201 | 21 | Yes
TMK063CG180JT-F | C391,C392,C402,C403,C404,C405 | CAP CER 18PF 25V 5% COG 0201 | 6
TNPW040215K0BEED | R82 | Resistor Chip 0402 15K Ohm 1/16W 0.1% | 1
TPD1E05U06DPYT | T1,T2 | TVS DIODE 5.5VWM 14VC 2X1SON | 2 |  | NOTE: T1 & T2 are the only new parts on the v1.0.6 main board
TPS65132B5YFFR | U17 | IC VREG +-5.5V Dual Output | 1
TPS65982ABZQZR | U27 | IC USB PD PHY and Power Switch/USB | 1
TPS78001DRVT | U19 | IC LDO 1.8V-5.5V 150mA 1.2--5.5V IQ:0.5uA TPS78001DRV | 1
TXS4555RUTR | U330 | IC TRNSLTR BIDIRECTIONAL 12UQFN | 1
USB2642/ML | U2 | IC USB 2.0 High Speed 2-Port Hub with SD Reader Controller | 1
VCNL4040M3OE-H5 | U26 | IC Light Sensor PS and ALS VCNL4040M3OE-H5 | 1
WM8962BECSN/R | U24 | IC AUDIO Stereo CODEC WM8962 | 1
WPN252012H100MT | L20 | IND PWR 10uH@1MHZ 1.35A 20% SMT | 1
WPN252012H1R0MT | L28,L32 | IND PWR 1uH@1MHZ 4.2A 20% SMT | 2
WPN252012H3R3MT | L21 | IND PWR 3.3uH@1MHZ 1.9A 20% SMT | 1
WR02X2000FAL | R115,R504,R506 | Resistor Chip 0201 200R Ohm 1/20W 1% | 3
WSL0603R0200FEA | R38,R134,R137,R138,R140,R152,R167,R168,R182,R183,R195 | Resistor Chip 0603 20m Ohm 1/10W 1% | 11

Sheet: usb-c board
Manufacturer’s Part Number | Designator | Description | Qty per Board | Also on Main Board?
02016D105MAT4A | C11,C13,C14,C225 | CAP CER 1uF 6V3 20% X5R 0201 | 4 | Yes
TMK063B7103MP-F | C18 | CAP CER 0.01uF 25V 20% X5R 0201 | 1 | Yes
04023D225KAT2A | C3,C4,C12,C19 | CAP CER 2.2uF 25V 20% X5R 0402 | 4 | Yes
3SM222FMT1KA | U31 | IC CMOS MEMS microphone | 1 | Yes
24-5857-040 | J11 | SOCKET BTB 0.35mm 40pin H=0.7mm 5857 | 1 | Yes
NU-3107-S24-00-1-D01 | J10 | USB24_TYPEC_SH6 | 1
CRCW0201100KFKED | R1,R9 | Resistor Chip 0201 100K Ohm 1/20W 1% | 2 | Yes
D-ED-110001-120-1-D02 | CON1,CON3,CON6,CON7,CON8,CON9,CON10,CON15,CON16 | RF shrapnel,W=1.4mm,L=2.4mm,Hf=1.0±0.1mm,Hw=0.55mm | 9 | Yes
ECT818000500 | ANT1,ANT2 | MHF4 coax antenna connectors | 2 | Yes
ERJ-1GN0R00C | R2,R3,R5,R17,C17,L34 | Resistor Chip 0201 0R Ohm 1/20W 1% | 6 | Yes
C0603C104M5RACTU | C15 | Ceramic Cap,X7R,0.10μF±20%,50Vdc,0603 | 1
GRM033R60J104KE19J | C10 | Ceramic Cap,X5R,0.10μF±10%,6.3Vdc,0201 | 1 | Yes
HPZ1005U121-1R1TF | L68,L69,L70 | FB 120ohm@100MHz 100ohm@1GHz DCR0.13ohm 1.1A T:0.5mm | 3 | Yes
MZAH1608G471-1R6TF | L2,L3 | FB 470ohm@100MHz 350ohm@1GHz DCR0.075ohm 1.6A T:0.8mm | 2 | Yes
PTVS16VS1UR,115 | D10 | PTVS16VS1UR | 1
RC0201FR-0733RL | R236,R237,R238 | RES 33 OHM 1% 1/20W 0201 | 3
TPD6S300ARUKR | U2 | TPD6S300A | 1
RC0201FR-0715KL | R10 | Resistor Chip 0201 15K Ohm 1/20W 1% | 1 | Yes
LQP03TG1N8B02D | R6 | Ceramic inductor,1.8nH±0.1nH,500mA,Q18,0.20Ω,12500MHz,0201 | 1
LQP03TG2N7B02D | R7 | Ceramic inductor,2.7nH±0.1nH,450mA,Q18,0.25Ω,11000MHz,0201 | 1
LQP03TN3N0B02D | R8 | Ceramic inductor,3.0nH±0.1nH,450mA,Q18,0.25Ω,9500MHz,0201 | 1
LQP03TG3N9B02D | R15 | Ceramic inductor,3.9nH±0.1nH,350mA,Q18,0.35Ω,6500MHz,0201 | 1
LQP03TN22NH02D | C16 | FIXED IND 22NH 150MA 1.9 OHM SMD | 1
CBR02C569B3GAC | R4 | CAP CER 5.6pF±0.1pF，25V C0G, NP0 0201 | 1
GRM0335C1E101JA01D | C6,C9 | CAP CER 100pF 25V ±5% C0G, NP0 0201 | 2
MXD8543E | U1 | 0.4~3.8GHz SP4T Antenna Tuning Switch | 1
WL2836E18-5 | U4 | 1.8V fixed LDO | 1
WL2836E28-5 | U3 | 2.8V fixed LDO | 1
DNI Parts
DNI | C1,C5,C7,C8,C89 | DNI
DNI | CON2,CON4,CON5 | DNI
DNI | R11 | DNI

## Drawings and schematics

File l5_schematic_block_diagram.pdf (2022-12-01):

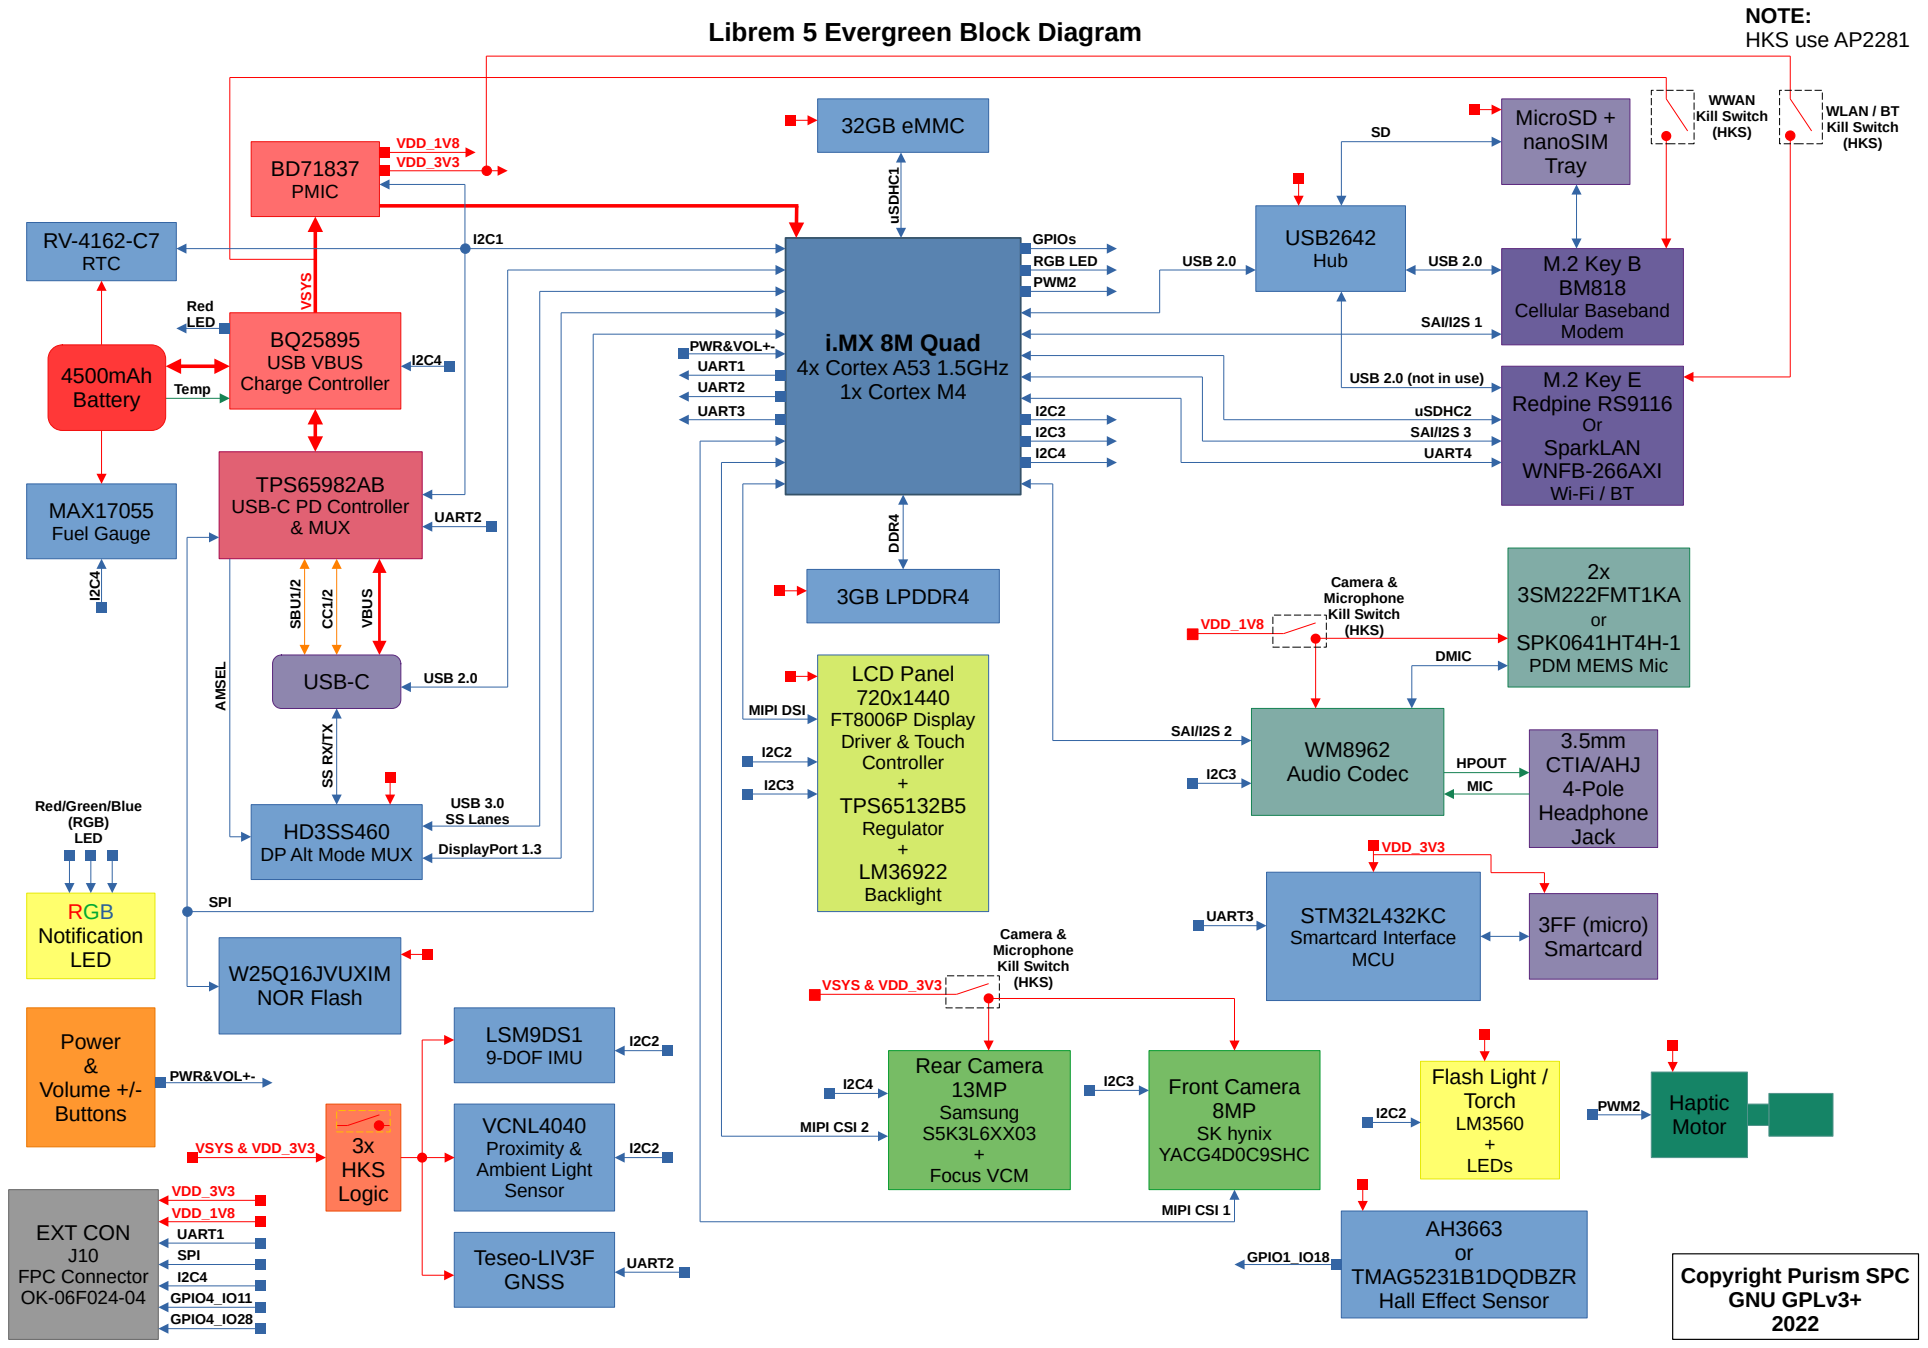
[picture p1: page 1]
i.MX 8M Quad; 4x Cortex A53 1.5GHz; 1x Cortex M4; 3GB LPDDR4; 32GB eMMC; USB2642; Hub; MicroSD +; nanoSIM; Tray; PMIC; USB VBUS; Charge Controller; M.2 Key B; Cellular Baseband; Modem; WWAN; Kill Switch (HKS); USB 2.0; M.2 Key E; Redpine RS9116; uSDHC2; WLAN / BT; TPS65982AB; & MUX; RTC; USB 3.0; SS Lanes; DisplayPort 1.3; SAI/I2S 1; SAI/I2S 3; UART4; UART2; MAX17055; Fuel Gauge; VCNL4040; Proximity &; Ambient Light; Sensor; LSM9DS1; 9-DOF IMU; Audio Codec; 3SM222FMT1KA; SAI/I2S 2; Teseo-LIV3F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

Librem 5 Evergreen Block Diagram

USB 2.0 (not in use)

SparkLAN
WNFB-266AXI

USB-C PD Controller

SPK0641HT4H-1
PDM MEMS Mic

Red/Green/Blue
(RGB)
LED

DP Alt Mode MUX

Copyright Purism SPC

Hall Effect Sensor

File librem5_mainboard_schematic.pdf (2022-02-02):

v1.0.6.1

# Librem 5

# Purism

1 21

# VER note

Sheet | of
Rev: | Date: | Design by:

Page Title:

Drawing Title:

V06

## 1, Del NFC PN7150, Add CON24, UART1 for GNSS or Debug, SPI2 to CON24, UART2 for BT

2, Move SMC_BOOT0 to Page 22 , TP6.
3, HKs Add Pull-up Resistor , And add Read state GPIO.
4, TYPE-C U27 LSX no connect.
5, Correct Y2, Y3 Connect.

## 6, Add Voltage Test Point , >40 point

7, Add SIM DET D6.
8, CAMERA Modify. Add LDO for DVDD 1.2 and 1.05. 9, TFT con Modify.

## 10, STM32 PA10 NC. UART add Pull-up R108, R135

V07

## 1, UART1 to LSX, UART2 to GNSS, UART4 to bt, SPI1 to CON24

2, U329 19PIN add Pull-up R229 .
V08

## 1, UART2 to LSX 2, HW state IO add resister. R48, R66, R145 3, 4G, WIFI ant CON add Debug L,C

4, Add shielding Case Hold.
5, DEL F12, Modified IO U329 for L9 layer to GND.

## 6, INT_M/A/G, NFC_EN, NFC_IRQ modified IO to E1 for L2 to GND 7, ADD R232

V09

1, AUX_P , AUX_N swapped.
2, Add R236.

## 3, Del R153

4, LED_G to 8M D3 pin. NFC_IRQ to 8M E1 pin, INT_M/A/G to 8M L4 pin. 5, R122,R58 to 27K, R123 to 47K.

## 6, 4G used SAI6. ADD u5

V091

1, U5 8pin to SAI1_TXD5, 9pin to SAI1_RXD5. 2, ADD U7 for CAM_AFVDD, 2.8V 120mA.

## 3, U2 modified USB2642

V092

1, BOOT Resistor Modified.
2, EMMC 32G.
3, U3 NC.
4, PWM IO modify. MOTO E6, PMIC_5V T7, LED_B K6.
V093

1, R830 NC, R811 10k.
V094

1, BAT CON Modified for 1000 times.

## 2, ADD L66 L67

V095

1, R115 Modified to 200.
V096

1, ADD R153 for TPS65983B Slave.
2, Modified LM36922 to I2C3, J10 to I2C4.

1, Add N-mosfet Q8 on SD2_NCD.

V097

2, TPS65982 LDO_1V8D Connected BUSPOWERZ.
3, VDD_3V3 add 4x22uf C231....
4, VSYS_3V4_4V3 add 7x22uf C281....
5, U27 TPS65982 F2 UART_RX 100k R223 connect GND.

## 6, Add NET BT_WAKE

7, AUDIO_POWER_KEY connect Q2 PIN1.

0, CHG_STATUS_B connect Red LED.

## 8, ADD U68 NTSX2102 9, BOOT_CFG PU to NVCC_SNVS_3V3 10, R176 PU to NVCC_SNVS_3V3

11, R104 10 value.
12, R82 0402 0.1%
13, R934 100K
14, U2 USB2642 27,28 connect GND, 26 connect VDD. 15, ADD Q9, Modified WIFI_REG_ON, BT_REG_ON.

## 16, ADD R238 UART2_RXD PU USB_PD_LDO3V3 17, ADD Q10, R239, R240,R241

18, Add TYPEC_HRESET,
19, R42 1M ,

## 20, U147 connect TPS65982 21, SW3,SW5,SW7 2-3PIN 22, J50 modified 23, J12 modifed

V098

1, 0 ohm jumpers SPI.

## 2, C181 NC 3,main board usb 2.0 connector 4,PFET pull up UART2_RX 5,red LED powered by VSYS 6, TPS65982 I2C2 10K pull-ups 7, TPS65982 remove_usb 2.0 8, TP34 connect USB_VBUS for test 9, SPI MISO ADD pull-up 10K 10, ADD u50,U51 , C335,C336

## (11) Battery connector (J20): changed to P / N: BA32-111203-01 3pin

## (12) Cancel J50 (flash holder) and move the flash to the rear camera FPC

## (13) change J22 to P / N: OK-06F034-04

## (14) J9 smartcard (80500122) is changed to SA070112150-105

## (15) Headphone socket (J2) changed to JA-36A1-111

(16)
(17) SIM +TF Card changed to SA2101110135-103-01, TF_NCD and 4G_ SIM_ CD two port exchange (Change to plastic tray)

## (18) R166, R109 changed to 0R

## (19) Connect SMC_ Boot0 to D7 pin of imx8mq

## (20) R41(47K) changed to 0R (21) ADD CLOCK Crystal(Y1 )VALUE:32.768K 10pF +/-20ppm Use TLV75801PDBVR instead of LCDL015MR for U21 and U37 Make R33=11.8k Make R70=9.09k Remove R234 (0)

(22)

V099

## (23) add a test point to pin C2 of the TPS65982 (U27's GPIO1_CFG0)

## (24) add inverter (Q12)

ADD C351/352/356/388/396/397/398/399/400/406/407/408/409/410/411/412/413/414/415/416/417//418/

## ADD C339

## ADD C436/437/439/440/441/442/443/444 0201/1UF

(25)
(26)

(27)

(28)

## ADD: C448 C449 C450 22UF 0603 6.3V

## C434 C435 NC

## (29) R209 R210 changed to 1.5K

(30) DEL R1903
(31) ADD: LNA BGA725L6 & SAW filter B39162B4327P810. etc

(32)Bring USB_PD_LDO3V3 to pin 23 of J12 on the main board:

(33)Remove TVS11, TVS30, TVS31, and TVS32 on the main board:

(34) C343/C377 changed to 220PF

### (35)change the connection of PMIC(U1) Pin49

### (36) Change U101 MIPI_ VDDHA3 connection

(37) R63/ R64,/R100/ R103 NC.

### (38) C379 and C380 = 100nF (0.1uF) (39) ADD R251/R252 1M

## (40) ADD :Y2 (32.768K)/C332/C333(6.8Pf) (41) ADD :R253/NC (42) ADD R254/0 OHM (43) Add connection between J4's pin12 and U101's G6 (44) add R255/0 ohm (45) C87/C256 changed to 56pF (46) ADD C451/C454 56pF

V1.02 & V1.03

### 1. Q12 CHANGE TO BSS138PW 2. R5 CHANGE TO 10R 3. D10 change to PTVS16VS1UR (USB Board) 4. ADD PTC FUSE :400CC1206LR-C (USB Board) 5. DEL R180, R184 6. ADD L9

7. ADD D25(NSR20F30NXT5G);
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

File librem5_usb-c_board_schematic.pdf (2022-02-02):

# USB TYPE-C

# TYPE-C BOARD

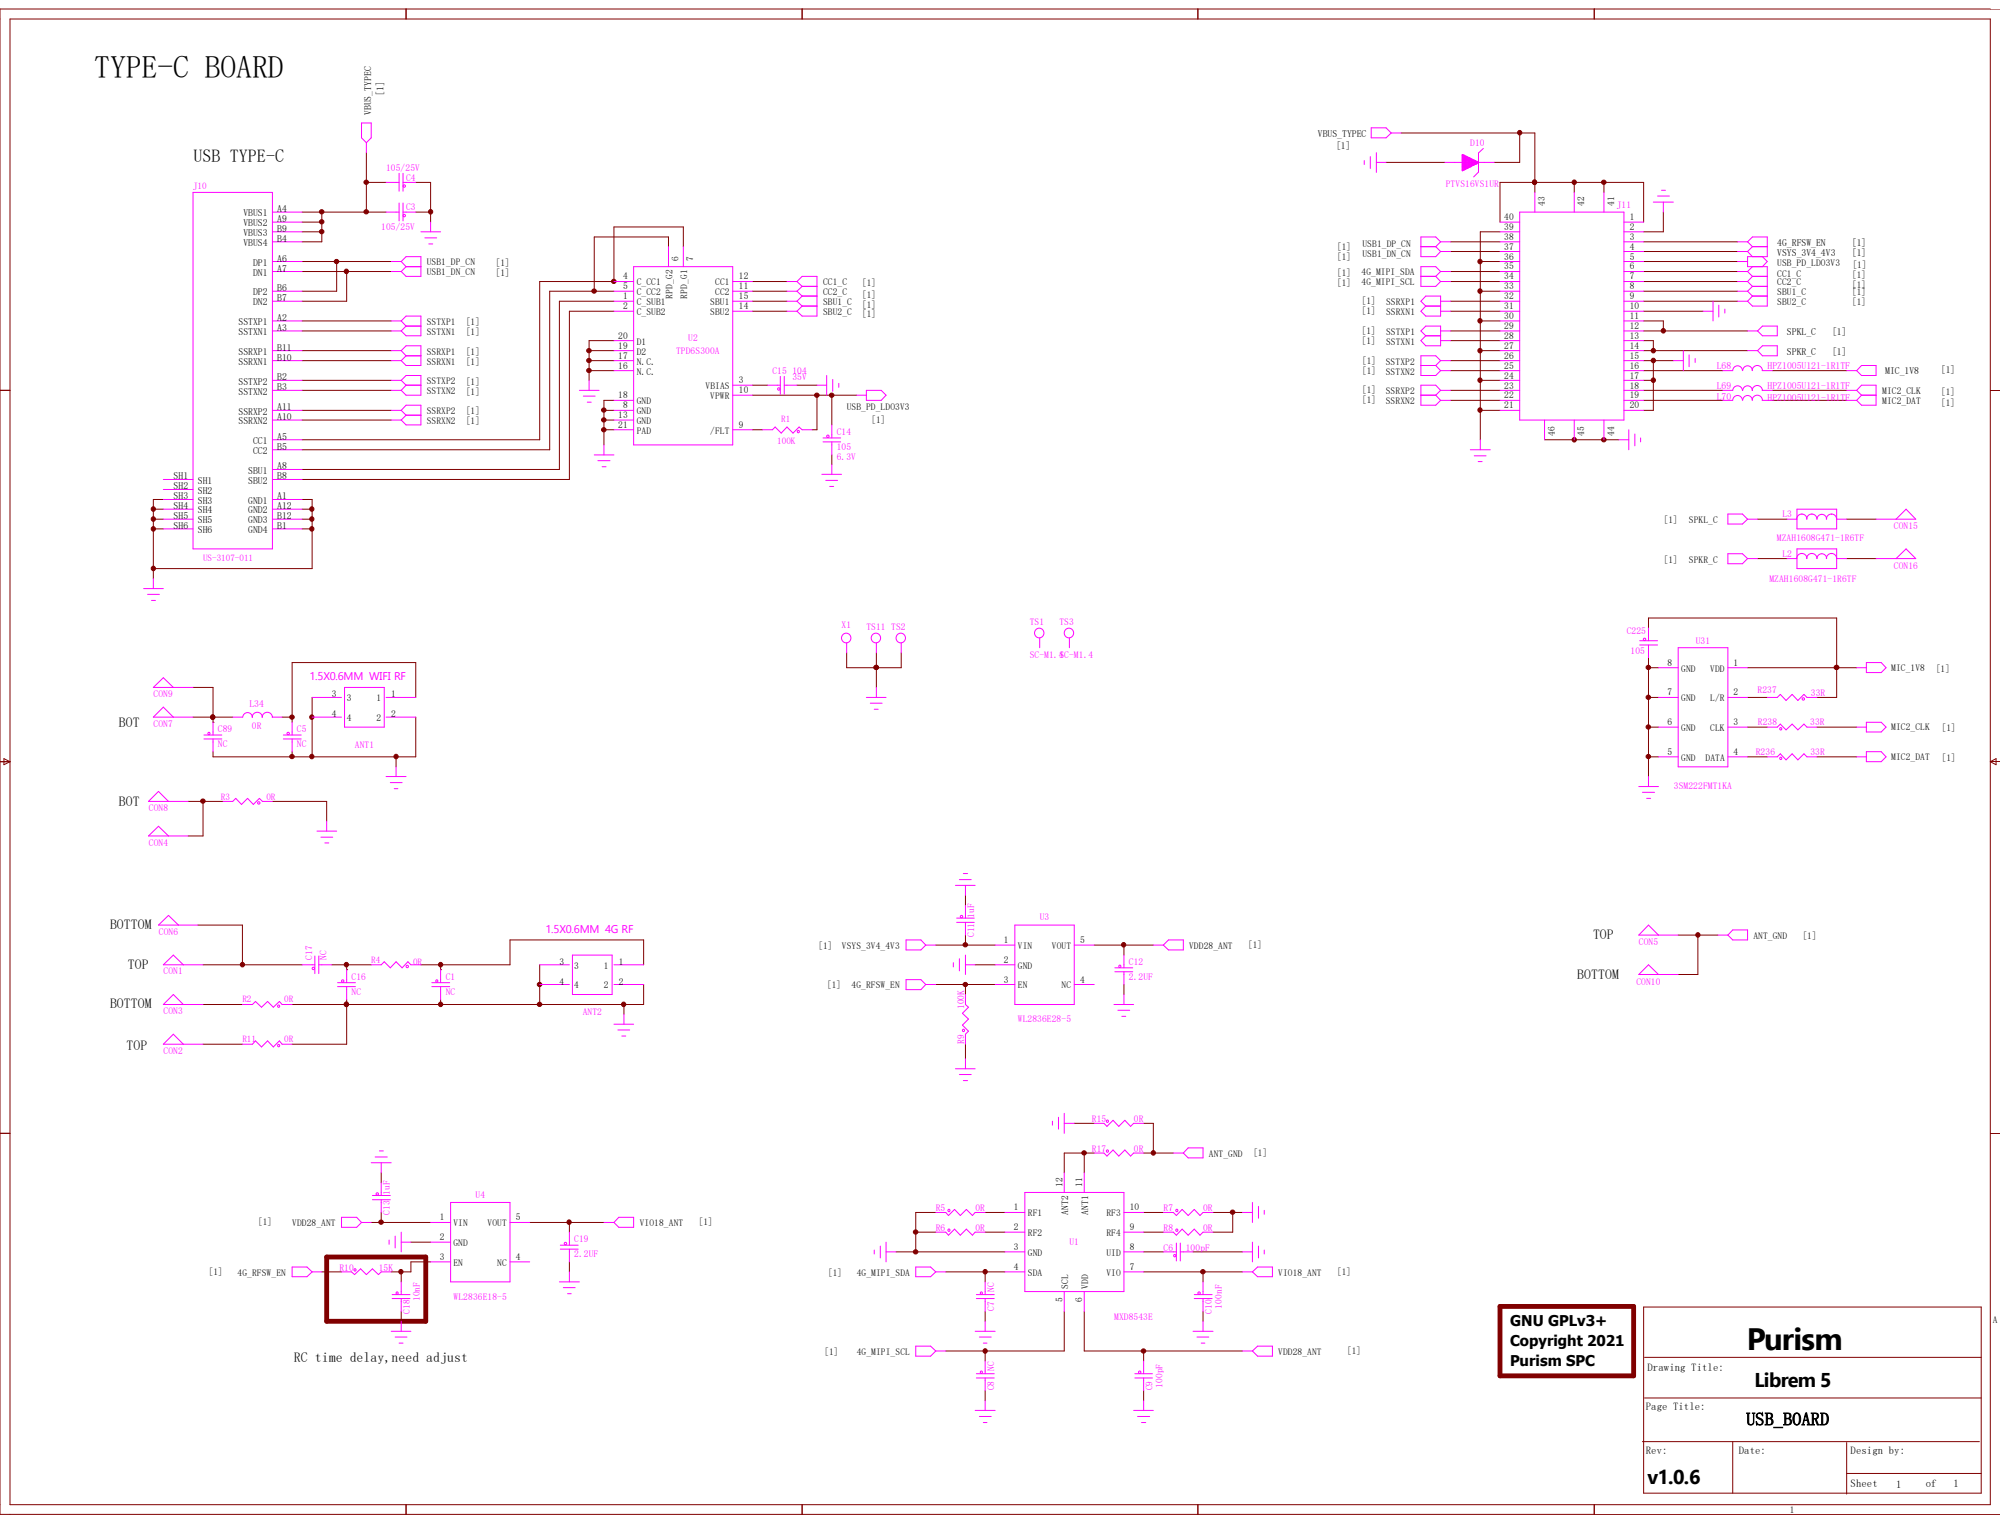
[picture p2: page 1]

RC time delay,need adjust

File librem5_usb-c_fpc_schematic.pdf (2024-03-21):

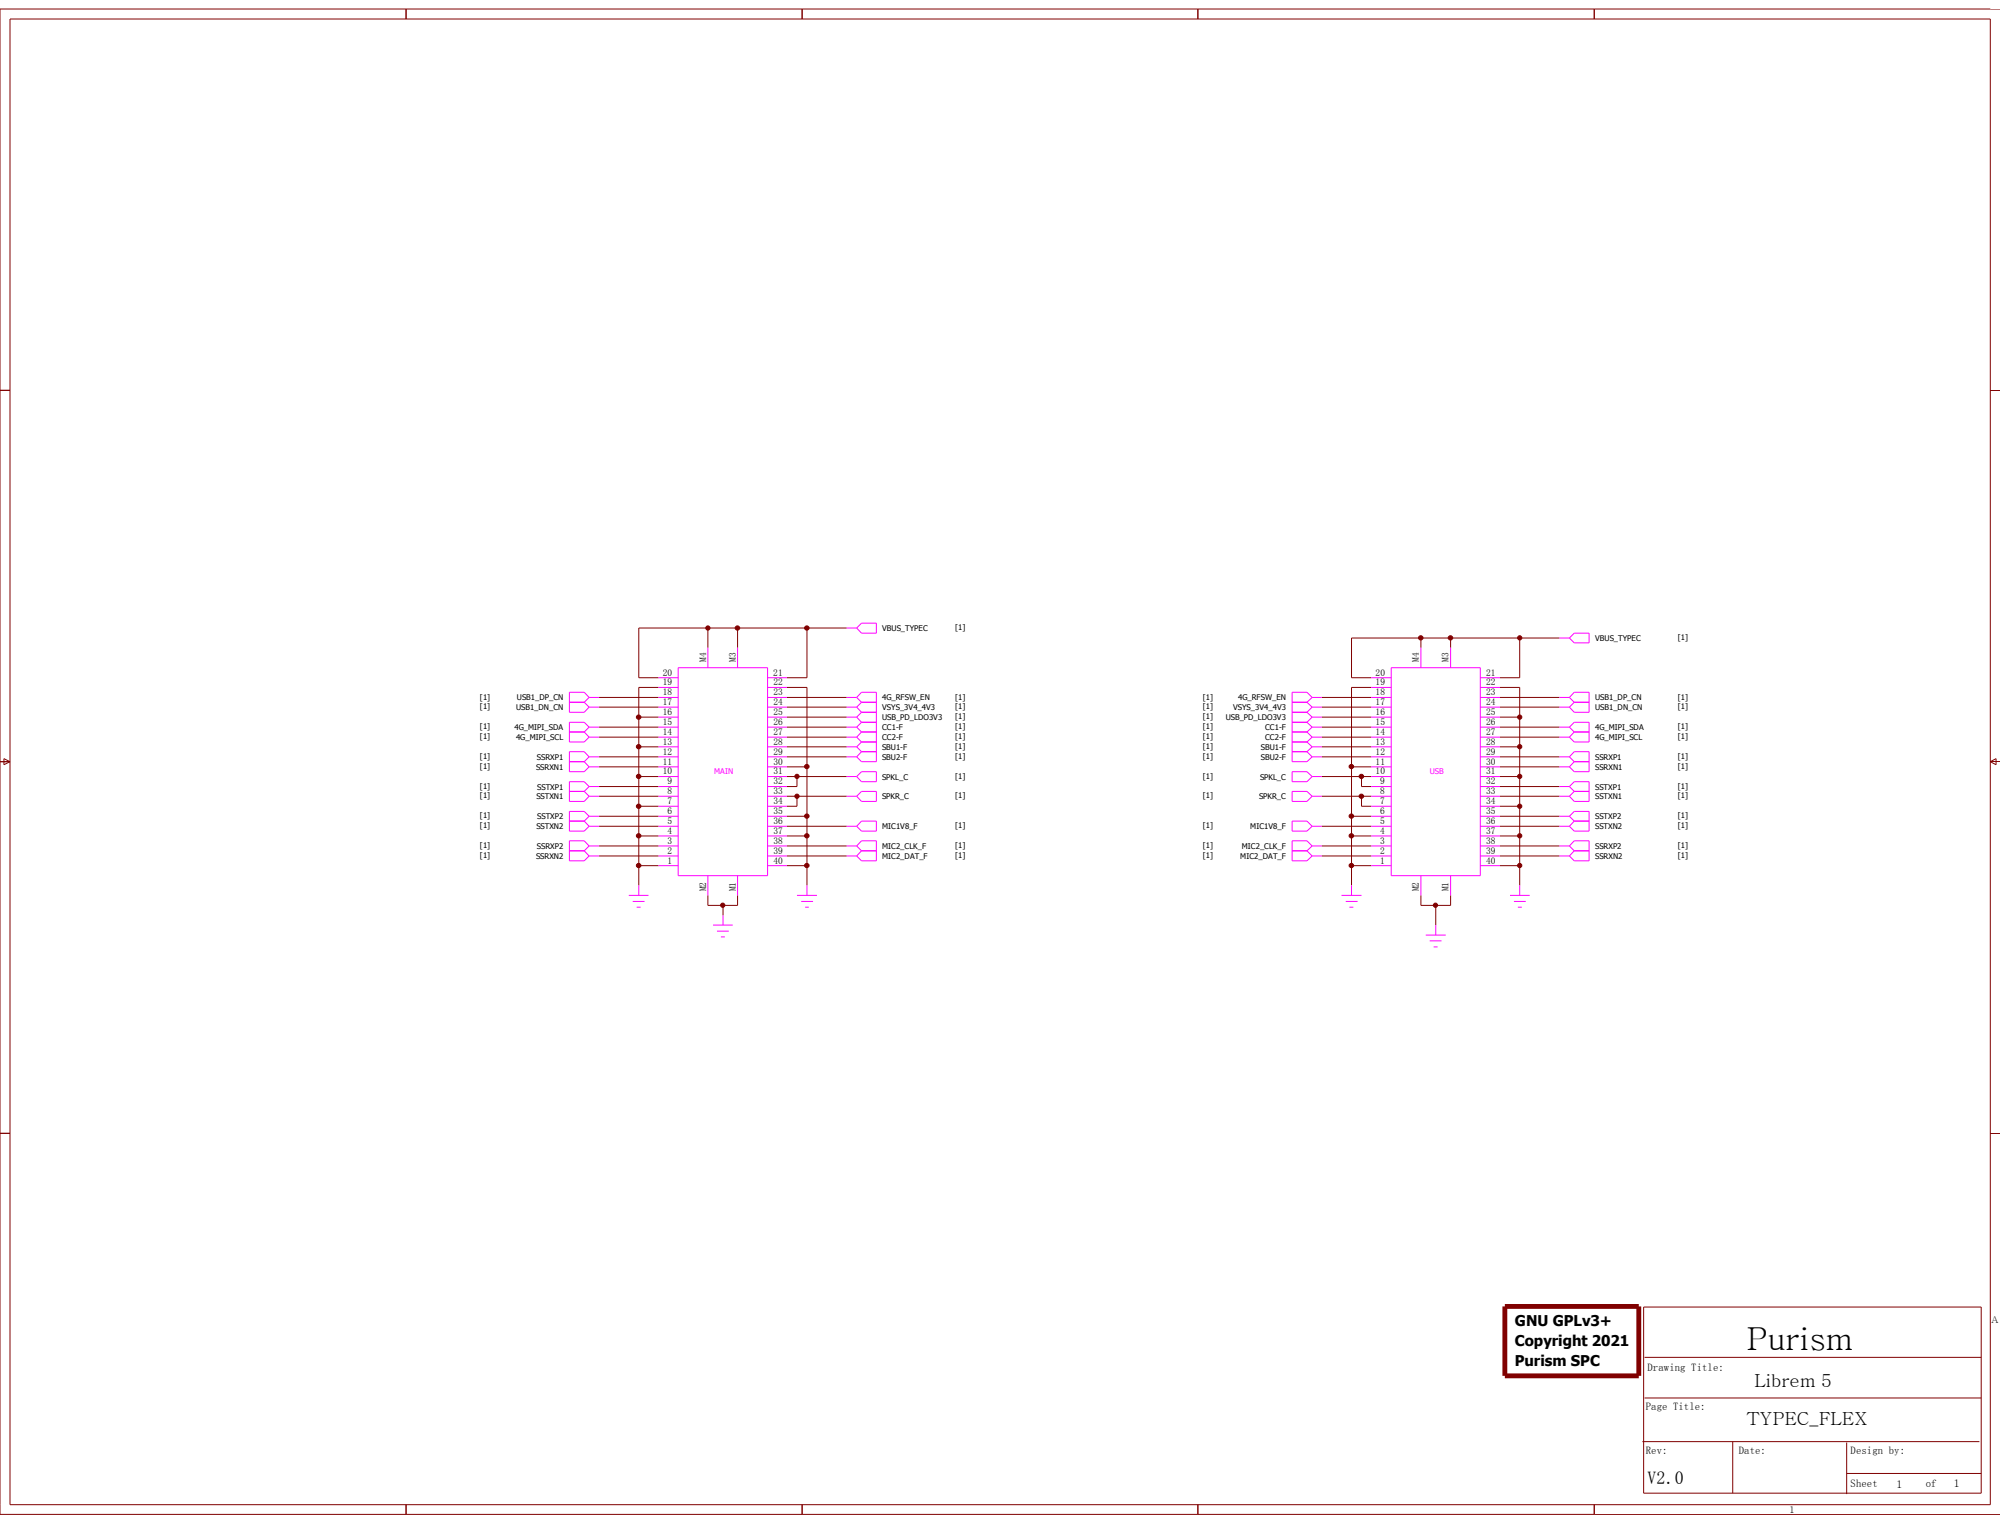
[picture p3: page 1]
MAIN; USB; TYPEC_FLEX; Librem 5; Purism; Drawing Title:; Page Title:; Rev:; Date:; Design by:; Sheet; GNU GPLv3+ Copyright 2021 Purism SPC; VBUS_TYPEC; 4G_RFSW_EN; VSYS_3V4_4V3; USB_PD_LDO3V3; SBU1-F; SBU2-F; SPKL_C; SPKR_C; MIC1V8_F; MIC2_CLK_F; MIC2_DAT_F; [1] USB1_DP_CN [1] USB1_DN_CN; [1] 4G_MIPI_SDA [1] 4G_MIPI_SCL; [1] SSRXP1 [1] SSRXN1; [1] SSTXP1 [1] SSTXN1; [1] SSTXP2 [1] SSTXN2; [1] SSRXP2 [1] SSRXN2; USB1_DP_CN; USB1_DN_CN; 4G_MIPI_SDA; 4G_MIPI_SCL; SSRXP1; SSRXN1; SSTXP1; SSTXN1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

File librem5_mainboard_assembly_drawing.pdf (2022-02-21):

23 | 1

24

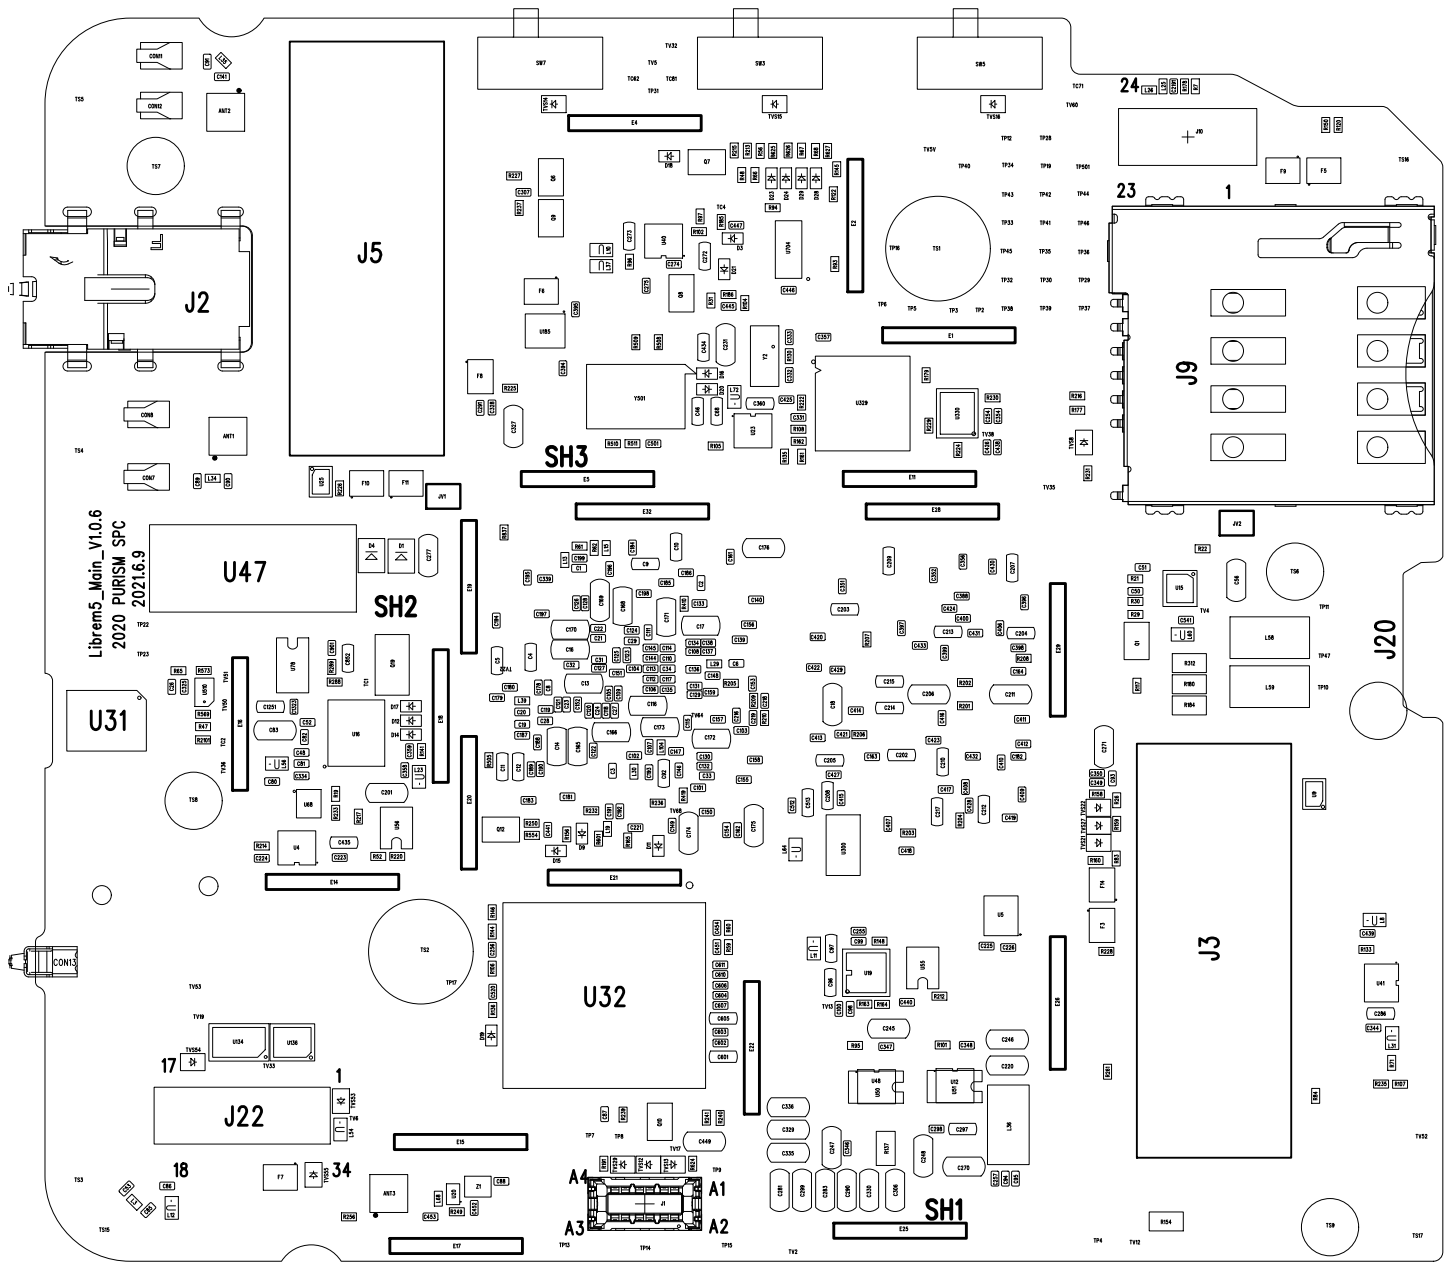
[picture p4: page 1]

J7

Q3

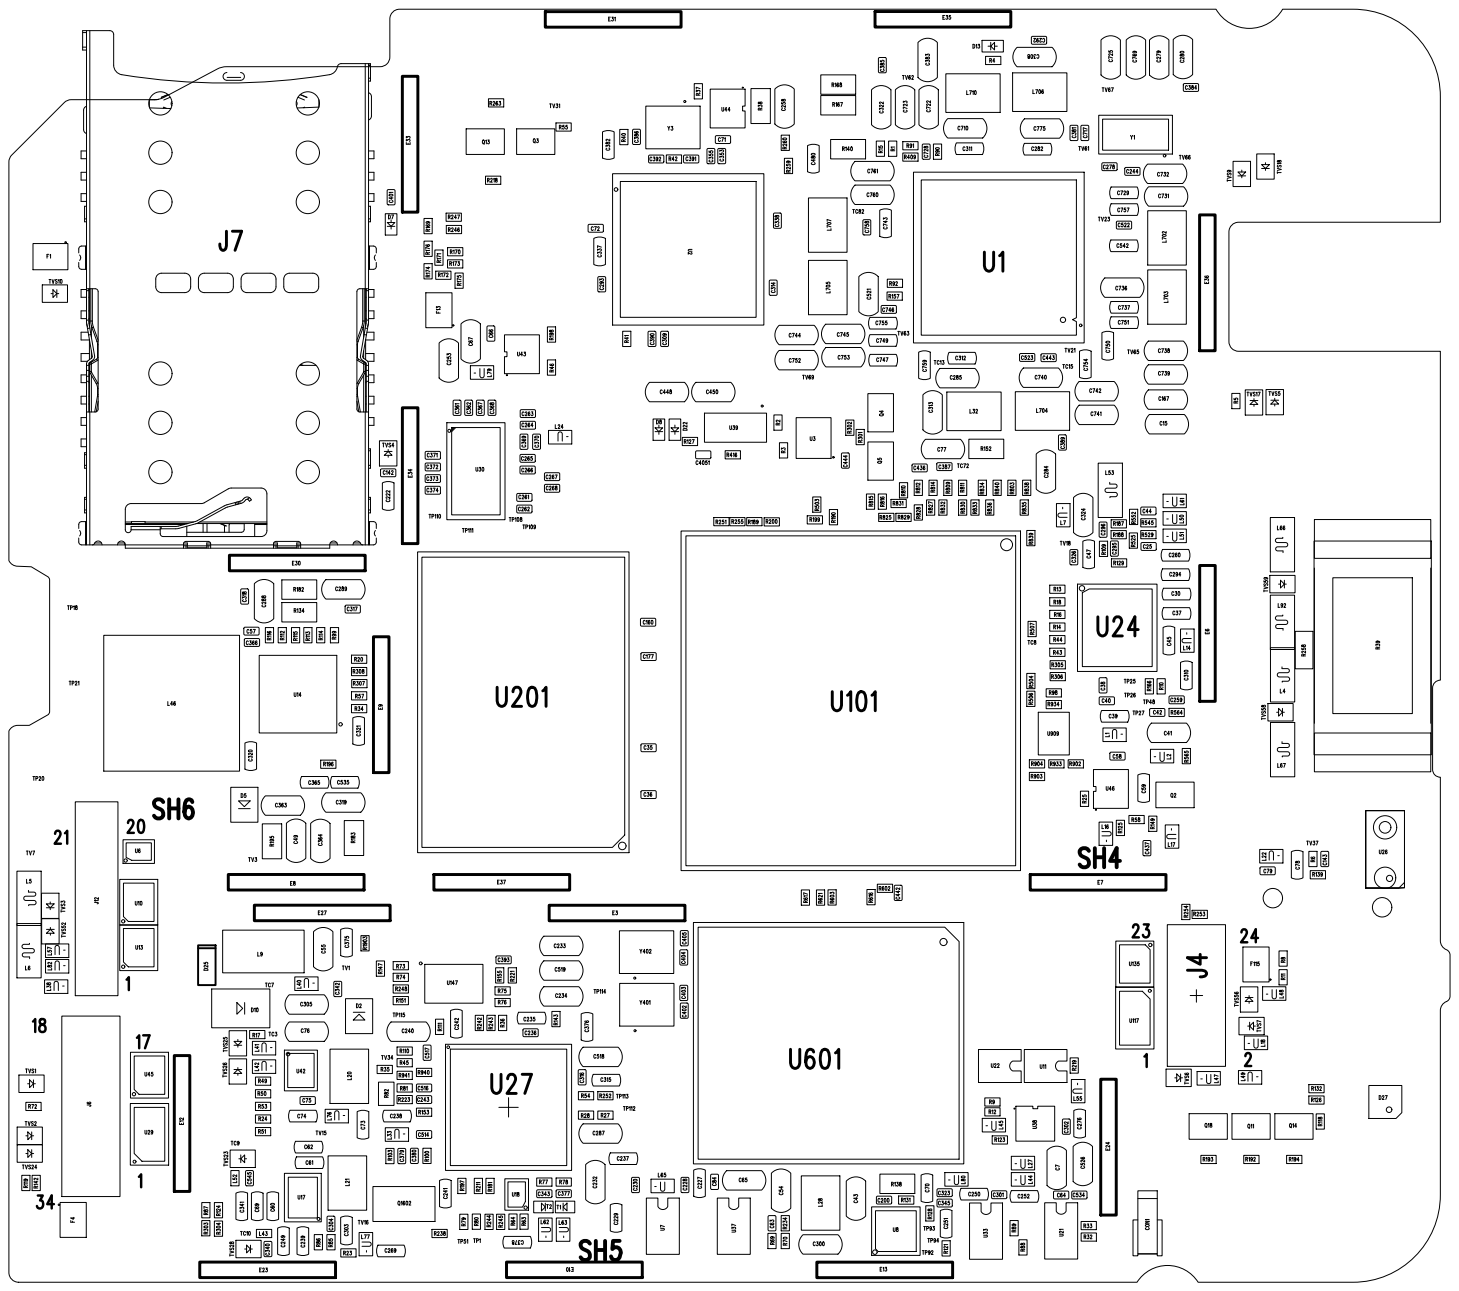
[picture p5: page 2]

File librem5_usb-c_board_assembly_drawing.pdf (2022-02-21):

L34

C5

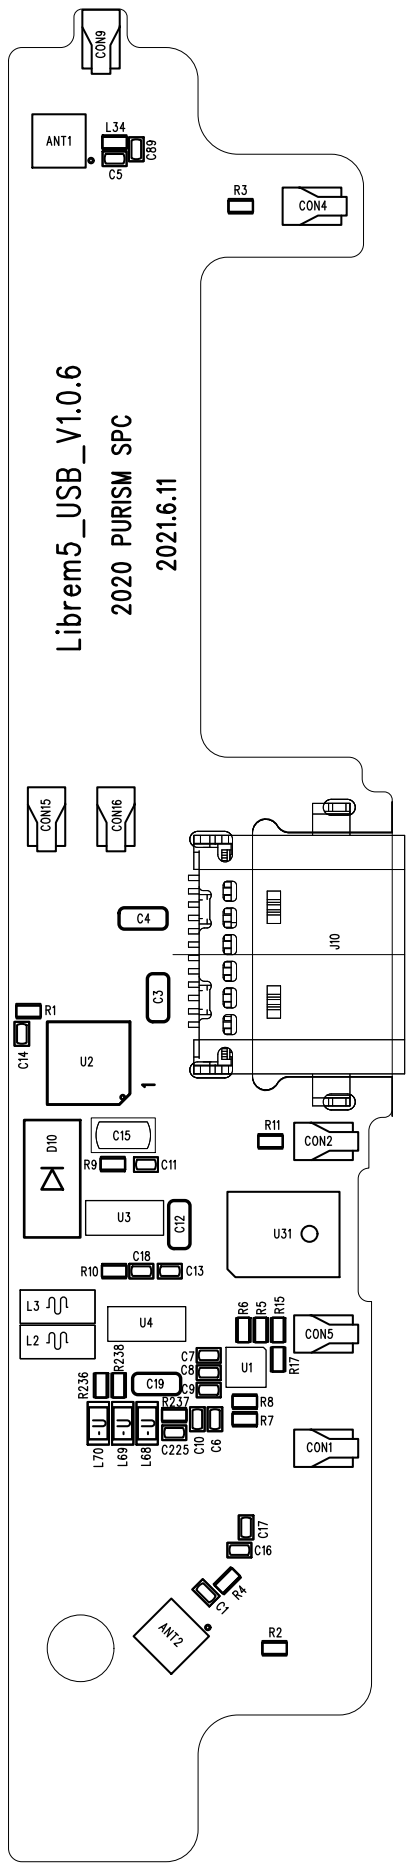
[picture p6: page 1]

# CON8

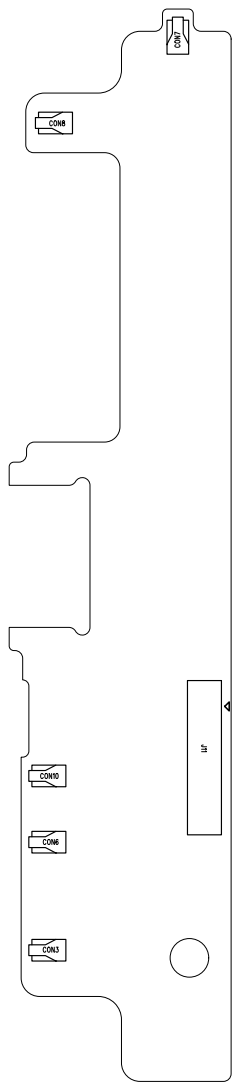
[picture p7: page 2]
CON7; CON3; CON10; CON6; CON7x1 CON7; CON3x1 CON3 CON10x1 CON10 CON6x1 CON6; CON8x1 CON8

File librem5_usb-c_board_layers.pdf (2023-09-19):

L34

C5

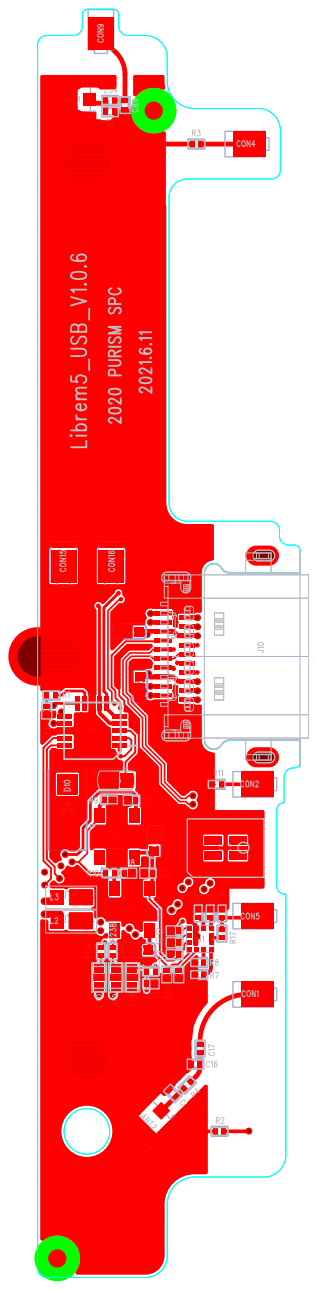
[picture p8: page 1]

U31 U31U³¹x1 | U³¹x2 U³¹x4 U³¹x3 U³¹x5 U³¹x6 | U³¹x7 U³¹x8

# TS2TS²x1

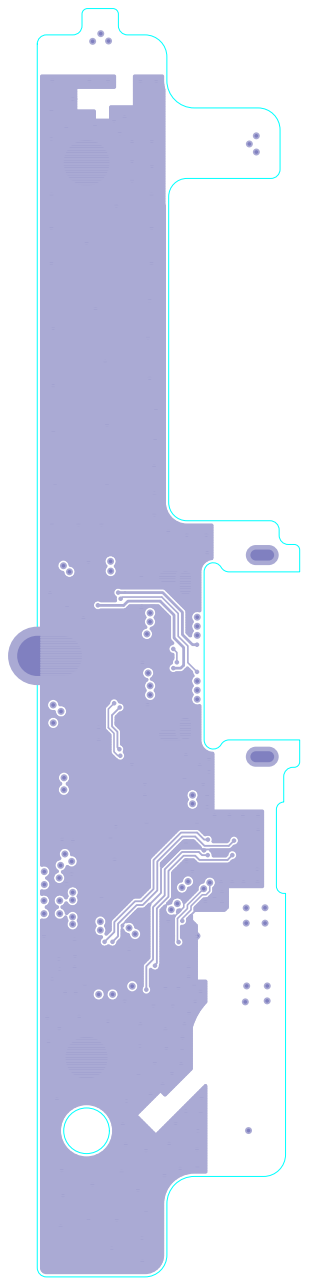
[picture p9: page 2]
J10J10xSH¹ J10xSH² J10xSH³ J10xSH⁴ J10xSH⁵ J10xSH⁶; X1X¹x1; TS11TS¹¹x1

# TS2TS²x1

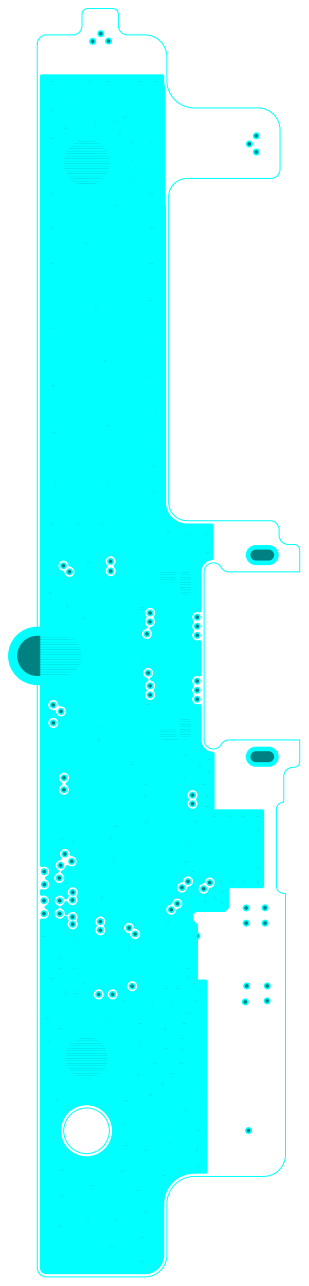
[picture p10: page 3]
J10J10xSH¹ J10xSH² J10xSH³ J10xSH⁴ J10xSH⁵ J10xSH⁶; X1X¹x1; TS11TS¹¹x1

# TS2TS²x1

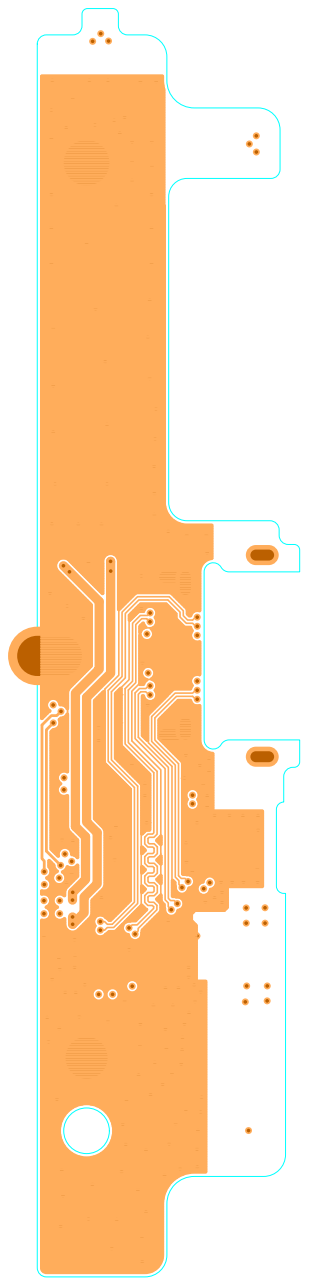
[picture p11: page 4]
J10J10xSH¹ J10xSH² J10xSH³ J10xSH⁴ J10xSH⁵ J10xSH⁶; X1X¹x1; TS11TS¹¹x1

# TS2TS²x1

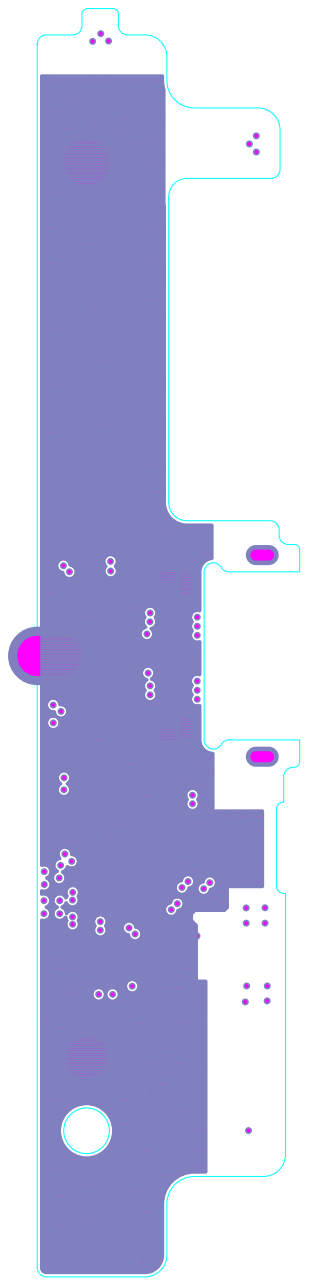
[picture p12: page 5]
J10J10xSH¹ J10xSH² J10xSH³ J10xSH⁴ J10xSH⁵ J10xSH⁶; X1X¹x1; TS11TS¹¹x1

# TS3TS³x1

# TS2TS²x1

CON7; J10J10xSH¹ J10xSH² J10xSH³ J10xSH⁴ J10xSH⁵ J10xSH⁶; X1X¹x1; TS1TS¹x1; TS11TS¹¹x1; TS3TS³x1; CON7CON⁷x1; CON3CON³x1; CON10CON¹⁰x1; CON6CON⁶x1; CON8CON⁸x1; TS2TS²x1

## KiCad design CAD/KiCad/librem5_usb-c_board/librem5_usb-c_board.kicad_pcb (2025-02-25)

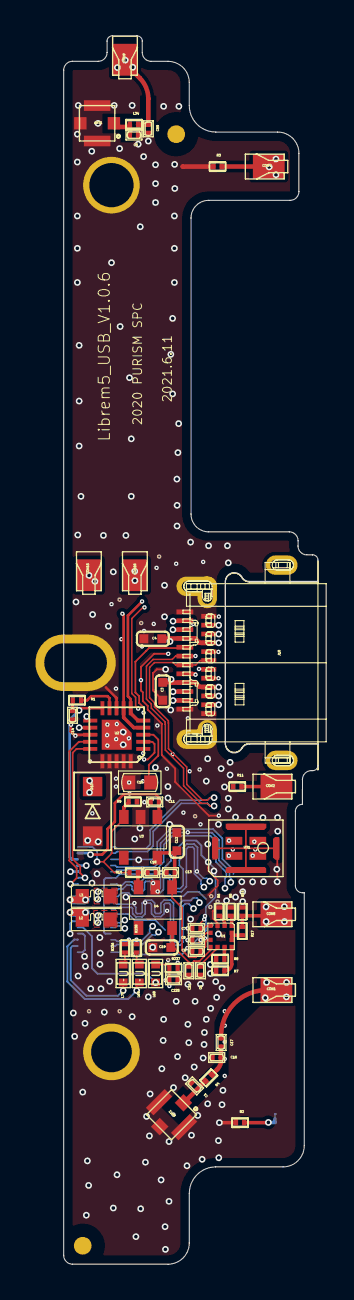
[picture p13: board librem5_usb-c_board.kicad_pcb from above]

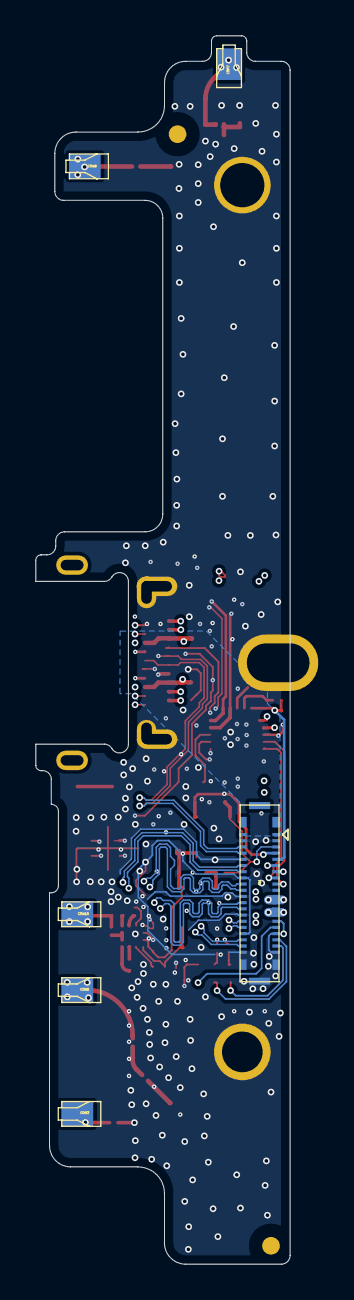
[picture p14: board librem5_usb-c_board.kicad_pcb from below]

Board: 6 copper layers, 14.4 x 69.4 mm, 69 parts (6 on the bottom side), 58 nets.

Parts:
ANT1, ANT2: APEX-4
C1, C5, C6, C7, C8, C9, C10, C11, C13, C14, C16, C17, C18, C89, C225: CAP-0201
C3, C4, C12, C19: CAP-0402
C15: CAP-0603
CON1, CON2, CON3, CON4, CON5, CON6, CON7, CON8, CON9, CON10, CON15, CON16: ANT_CON1-CZX
D10: SOD123W
J10: CON-USB-TYPEC-3107A
J11: BTB40-0.35-KYOCERA
L2, L3: IND-0603
L34: RES-0201
L68, L69, L70: IND-0402
R1, R2, R3, R4, R5, R6, R7, R8, R9, R10, R11, R15, R17, R236, R237, R238: RES-0201
TS1, TS3: SC-M1.4F
TS2: PTH_D250_320
TS11: PTH_D230_320
U1: MXD8543E_QFN12
U2: TPD6S300AA
U3, U4: WL2836E_SOT-23-5L
U31: 3SM222FMT1KA
X1: PTH_SLOT_220_355

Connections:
4G_MIPI_SCL: C8.1, J11.34, U1.5
4G_MIPI_SDA: C7.1, J11.35, U1.4
4G_RFSW_EN: J11.3, R9.2, R10.1, U3.3
$$$5995: R5.2, U1.1
$$$6176: R6.2, U1.2
$$$6343: C16.1, C17.2, R4.2
$$$6422: C17.1, CON1.1, CON6.1
$$$7024: R7.1, U1.10
$$$7027: R8.1, U1.9
$$$7350: C6.1, U1.8
$$$10996: CON2.1, R11.2
$$$11668: C18.1, R10.2, U4.3
$$$12116: R1.2, U2.9
$$$12510: R237.2, U31.2
$$$18331: R236.1, U31.4
$$$18332: R238.1, U31.3
$$$19146: C89.1, CON7.1, CON9.1, L34.2
$$$19504: J11.16, L68.1
$$$19505: J11.18, L69.1
$$$19506: J11.19, L70.1
$$$20764: ANT2.1, C1.1, R4.1
$$$23865: C15.1, U2.3
$$$25581: ANT1.1, C5.1, L34.1
$$$32555: R17.1, U1.11, U1.12
ANT_GND: CON5.1, CON10.1, R15.2, R17.2
CC1: J10.A5, U2.4, U2.7
CC1_C: J11.6, U2.12
CC2: J10.B5, U2.5, U2.6
CC2_C: J11.7, U2.11
GND: ANT1.2, ANT1.3, ANT1.4, ANT2.2, ANT2.3, ANT2.4, C1.2, C3.1, C4.1, C5.2, C6.2, C7.2, C8.2, C9.2, C10.2, C11.1, C12.2, C13.1, C14.2, C15.2, C16.2, C18.2, C19.2, C89.2, C225.2, D10.2, J10.A1, J10.A12, J10.B1, J10.B12, J10.SH3, J10.SH4, J10.SH5, J10.SH6, J11.2, J11.10, J11.15, J11.17, J11.20, J11.21, J11.24, J11.27, J11.30, J11.33, J11.36, J11.39, J11.44, J11.45, J11.46, R2.1, R3.1, R5.1, R6.1, R7.2, R8.2, R9.1, R11.1, R15.1, TS2.1, TS11.1, U1.3, U2.8, U2.13, U2.16, U2.17, U2.18, U2.19, U2.20, U2.21, U3.2, U4.2, U31.5, U31.6, U31.7, U31.8, X1.1
MAIN_ANT_GND: CON3.1, R2.2
MIC2_CLK: L69.2, R238.2
MIC2_DAT: L70.2, R236.2
MIC_1V8: C225.1, L68.2, R237.1, U31.1
SBU1: J10.A8, U2.1
SBU1_C: J11.8, U2.15
SBU2_C: J11.9, U2.14
SPKL: CON15.1, L3.2
SPKL_C: J11.11, J11.12, L3.1
SPKR: CON16.1, L2.2
SPKR_C: J11.13, J11.14, L2.1
SSRXN1: J10.B10, J11.31
SSRXN2: J10.A10, J11.22
SSRXP1: J10.B11, J11.32
SSRXP2: J10.A11, J11.23
SSTXN1: J10.A3, J11.28
SSTXN2: J10.B3, J11.25
SSTXP1: J10.A2, J11.29
SSTXP2: J10.B2, J11.26
SUB2: J10.B8, U2.2
USB1_DN_CN: J10.A7, J10.B7, J11.37
USB1_DP_CN: J10.A6, J10.B6, J11.38
USB_PD_LDO3V3: C14.1, J11.5, R1.1, U2.10
VBUS_TYPEC: C3.2, C4.2, D10.1, J10.A4, J10.A9, J10.B4, J10.B9, J11.1, J11.40, J11.41, J11.42, J11.43
VDD28_ANT: C9.1, C12.1, C13.2, U1.6, U3.5, U4.1
VIO18_ANT: C10.1, C19.1, U1.7, U4.5
VSYS_3V4_4V3: C11.2, J11.4, U3.1
WIFI_ANT_GND: CON4.1, CON8.1, R3.2

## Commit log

2019-12-02 Add the v0.9.7 "Birch" schematics
2020-01-07 Add the v0.9.8 "Chestnut" schematics
2020-03-20 Add the SoC pinout spreadsheet
    [soc_pinout.ods]
2020-07-08 Add the v1.0.0 "Dogwood" schematics
2020-07-11 Update the pinout spreadsheet to reflect the new GPIO controlling the SHDN pin of the front-facing camera
    [soc_pinout.ods]
2020-11-08 Add the v1.0.2 "Evergreen" schematics
2020-11-11 Add TF_NCD to the pinout spreadsheet which is found on pin J22 GPIO3_IO11
    [soc_pinout.ods]
2022-02-01 Add the v1.0.3.1 "Evergreen" schematics
2022-02-02 Add the v1.0.6 "Evergreen" schematics
2022-02-02 Add the v1.0.6.1 "Evergreen" schematics
2022-02-21 Add the v1.0.6 "Evergreen" assembly drawings
    These drawings are the same for v1.0.6.1 as well.
2022-12-01 Add the schematic block diagram
    The source file is a LibreOffice draw format. Also included is a PDF.
2023-05-25 Add interactive HTML BOMs for both boards
2023-07-02 Add the latest Librem 5 BOM
    The spreadsheet contains both the main board and usb-c board BOMs as
    separate sheets. Alternative part numbers exist for several parts but
    are not (yet) listed.
    [librem5_BOM.ods]
2023-07-19 Specify in the notes that the 4GB DRAM and 128GB eMMC is used on the Liberty Phone
    [librem5_BOM.ods]
2023-08-14 Correct the HKS part number in the BOM
    It should be MK-12C02-G015 instead of MK-12C02-G020 since the length of
    the actuator should be 1.5mm, not 2.0mm.
    [librem5_BOM.ods]
2023-09-19 Add PDFs of the boards' layers
2024-03-21 Add the USB-C flex cable schematic
2024-03-24 Add an interactive HTML BOM for the USB-C FPC (flex cable board)
2024-03-24 Add the CAD files for the mainboard, USB-C board, and USB-C FPC
    [C-03_POWER_TREE.kicad_sch, C-04_CPU_PWR.kicad_sch, C-05_LPDDR4.kicad_sch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]
2024-03-31 .gitignore: Do not track `fp-info-cache` files
2024-08-18 Add GigaDevices GD25Q16EEIGR as a potential SPI NOR flash for U147
    [librem5_BOM.ods]
2024-09-23 Add the mainboard's stackup in its KiCad project
2024-09-25 Add relative permittivity values for the dielectrics and rename the layers to use KiCad's convention
2024-10-12 KiCad Mainboard: Rename all sheets to correctly follow the sheet numbering
    Update the project to KiCad 8.99
    [02_POWER_TREE.kicad_sch, 03_CPU_PWR.kicad_sch, 04_LPDDR4.kicad_sch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]
2024-10-12 KiCad Mainboard: Convert all hierarchical labels to global labels since it is a flat schematic
    [03_CPU_PWR.kicad_sch, 04_LPDDR4.kicad_sch, 05_CPU_IO.kicad_sch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]
2024-11-09 Set the rev in the title block for each sheet and the layout to v1.0.6.1
    [02_POWER_TREE.kicad_sch, 03_CPU_PWR.kicad_sch, 04_LPDDR4.kicad_sch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]
2025-02-25 Update the KiCad projects to v9.0
    [02_POWER_TREE.kicad_sch, 03_CPU_PWR.kicad_sch, 04_LPDDR4.kicad_sch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]
2025-03-22 BOM: make R48, R66, and R145 become CRCW020110K0FNED (10kOhm 0201)
    This fixes VIH(min) not being reached when the internal pull-ups on the
    HSW_*_STATE SoC pins are disabled, allowing the software to reliably
    detect when the switch is in its on state.
    For now, this is a BOM-only change that has not yet been reflected in
    the schematic.
    [librem5_BOM.ods]
2026-05-21 Use KiCad's new PADS importer/converter tool to go directly from PADS ascii to KiCad 10, place this newly converted project in CAD/PADS/librem5_mainboard/librem5_mainboard_kicad_conversion/, keep the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
    The one in CAD/KiCad/ seems to be a bit better but this newly converted
    project is available in case it might have some improvements (e.g. in
    cross-probing or some other more accurate details). Either one (or both)
    may be used to completely move the project over to KiCad.
    [02_POWER_TREE.kicad_sch, 03_CPU_PWR.kicad_sch, 04_LPDDR4.kicad_sch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]
